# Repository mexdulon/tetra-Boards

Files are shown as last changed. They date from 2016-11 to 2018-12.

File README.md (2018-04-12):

View this project on [CADLAB.io](https://cadlab.io/node/872). 

# tetra-Boards
## mexdulon Modules for Experiments with Digital Electronics

This repository includes material like schematics, layouts, instructions and explanations for mexdulon tetra-Boards. 
The modular system is developed for understanding digital electronics by experimenting. Next to the standard digital components (gates, counter, register, etc.) we created also boards for analog signals and external outputs (motor driver, relay, power FET). All these published boards are licenced as Open Hardware, see below.
If you have any suggestions, modifications or extensions, please feel free to share it with us.

## List with all boards

|Code|Description |
|----|---|
|7SD |7-Segment Display |
|ADA |Adapter 2x5 Port |
|ADC |Analog Digital Converter |
|ADD |Adder 2x4 Bit |
|ALU |Arithmetic Logic Unit |
|AMU |Analog Multiplexer 2x4:1 |
|AND |AND & NAND 4x2:1 |
|ANS |Arduino Nano Shield with Display  |
|ARD |Arduino Shield (Uno, Leonardo) |
|B7D |BCD 7-Segment Decoder |
|BCC |BCD Up/Down Counter |
|BNC |Binary Up/Down Counter 4 Bit |
|BTN |Quad Buttons |
|C12 |Counter 12bit |
|CDL |Counter Divider Logic |
|CLK |Clock Generator |
|CMP |Comparator 2x4 Bit |
|CNT |Dual Counter 4 Bit |
|D12 |Demultiplexer 1:2 |
|D14 |Demultiplexer 1:4 |
|D18 |Demultiplexer 1:8 |
|DAC |Digital Analog Converter (DAC) |
|DEC |Decoder 1:8 |
|DFF |Dual D Flip-flop |
|DIP |DIP Socket |
|DMD |Dot Matrix Display 4x4 |
|DMX |Diode Matrix 4x4 |
|ENC |Encoder 8:3 | 
|FET |Quad Power FET | 
|INV |Dual Inverter (NOT) | 
|IOP |Dual IO Port | 
|JAD |Jumper Adapter | 
|JKF |JK Flip-flop 2x | 
|JMP |Jumper 2x4 |
|JOY |Joystick with Button |
|KEY |Keyboard 4x4 | 
|LAD |Line Adapter | 
|LED |Dual LED Display |
|M81 |Multiplexer 8:1 |
|MTR |Dual Motor Shield |
|MUX |Multiplexer 2:1 |
|MXC |Modulo X Counter (3/6/9/12) | 
|N33 |Tripple NAND 3:1 |
|NOR |OR & NOR 4x2:1 |
|OPA |Operational Amplifier |
|PAN |Dual Port AND 4:1 |
|PIN |Pin Header |
|POR |Dual Port OR 4:1 |
|PRG |Pseudo Random Generator |
|PWM |PWM Generator |
|PXO |Dual Port XOR 4:1 |
|QRS |Quad RS Buttons |
|REG |Register 2x4 |
|RGB |RGB LED & Buzzer |
|RGF |Register File 4x4 |
|RLY |Quad Relay |
|ROM |ROM Diodes 4x4 |
|RSG |RS Generator |
|SAD |Shift Adapter |
|SOC |Quad Socket |
|SRC |SRAM Cell |
|SRG |Shift Register |
|SWG |Square Wave Generator |
|SWI |Quad Switch |
|TMP |Temperature Sensor |
|UNI |Universal Register |
|WNG |White Noise Generator |
|XOR |XOR & XNOR 4x2:1 |

# Copyright and License
Copyright Oliver Krebs 2017.

This documentation describes Open Hardware and is licensed under the CERN OHL v. 1.2. 

You may redistribute and modify this documentation under the terms of the CERN OHL v.1.2. (http://ohwr.org/cernohl). This documentation is distributed WITHOUT ANY EXPRESS OR IMPLIED WARRANTY, INCLUDING OF MERCHANTABILITY, SATISFACTORY QUALITY AND FITNESS FOR A PARTICULAR PURPOSE. Please see the CERN OHL v.1.2 for applicable conditions

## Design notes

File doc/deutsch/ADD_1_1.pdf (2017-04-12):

# Adder v1.1

mexdulon

12. April 2017

1

mexdulon | 1 ADDER

## 1 Adder

### 1.1 Allgemein

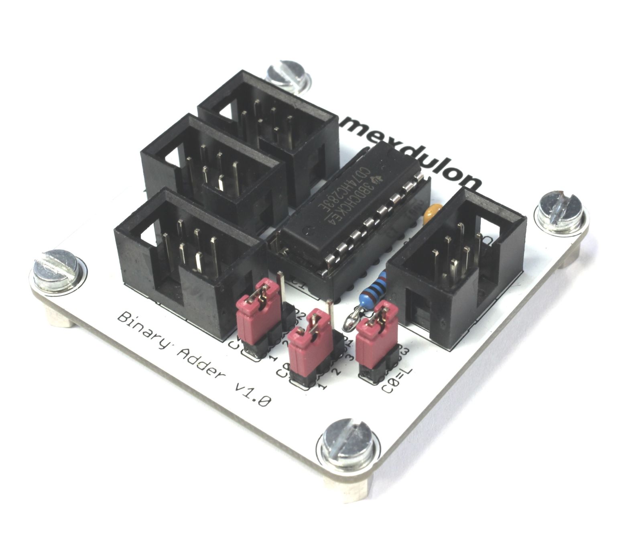
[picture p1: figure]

Wie der Name schon vermuten lässt, kann der Adder Zahlen addieren. Ein einzelnes Adder-Boardkann die zwei Zahlen derEingängeInAundInBaddieren undgibt dasErgebnis auf dem Ausgang Out aus.

### 1.2 Funktion

Die beiden 4-Bit Zahlen A und B sowie das Bit C0werden binär addiert. Für die gewöhnliche 4-Bit Addition wird C0 auf Low gesetzt. Die Summe liegt am Ausgang Out an, das Overflow Bit C4 kann auf dem Port Carry ausgegeben werden. Dieses zeigt mit einem High an, dass das Ergebnis größer ist, als am Ausgang dargestellt werden kann (also größer als 15). Über die Verknüpfung von C0 und C4 können außerdemmehrere Addierer zusammengeschaltet werden, um größere Zahlen als 4-Bit zu addieren. Dafür muss der Addierer für das niedrigwertigere Nibble das C4 dort ausgeben, wo der nächsthöhere Addierer das C0 erwartet. Ein möglicher Aufbau für einen 12-Bit Addierer wäre z. B. wie folgt:

Adder | C0 | C4 | Daten
1 | L | 1 | Bit 0..3
2 | 1 | 2 | Bit 4..7
3 | 2 | - | Bit 8..11

Hier wird dann allerdings noch einAdapter benötigt, um die Carry-Signale zu verteilen. Für einen 8-Bit Addierer können die beiden Carry Ports der beiden Adder direkt verbunden werden.
Der Adder kann übrigens auch zum Subtrahieren eingesetzt werden, also A minus B rechnen. Dafür muss der Eingang B invertiert werden und C0 auf High gesetzt werden. Das Invertieren kann man mit einem XOR Gatter auch schaltbar machen. Wenn man dann das Schaltsignalmit Carry verbindet,kannmanwahlweiseaddierenoder subtrahieren. Beachte allerdings, dass das Ergebnis der Subtraktion negativ sein kann und dann die Zuordnung Bitmuster-Wert anders ist (1111 ist dann nicht 15 sondern -1)!

2

mexdulon | 1 ADDER

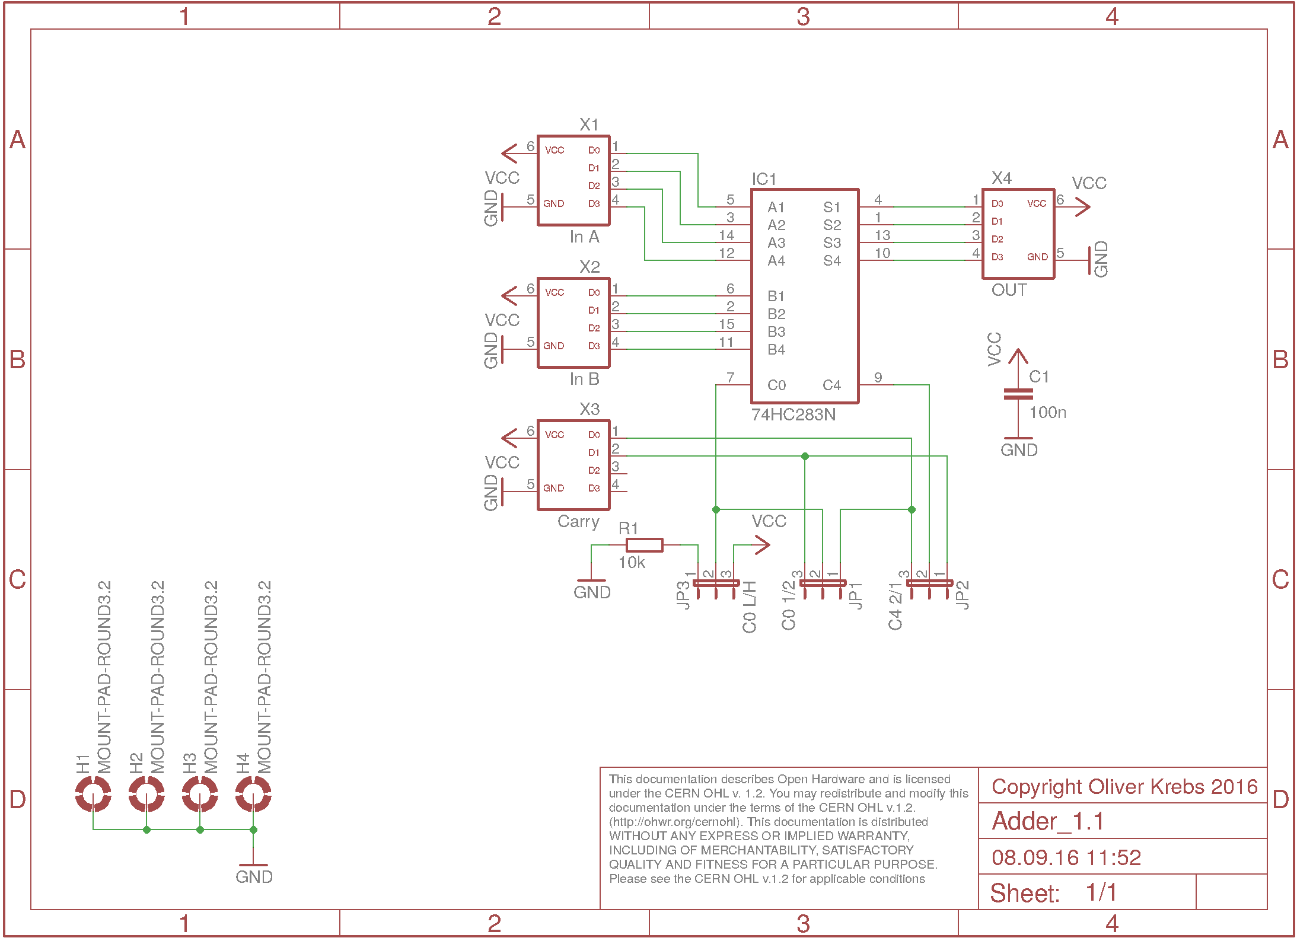
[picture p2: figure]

### 1.3 Aufbau

Kürzel | Wert | Bezeichnung
C1 | 100n | Kondensator
IC1 | 74HC283N | IC (Addierer)
JP1 | C0 1/2 | Stiftleiste 1x3
JP2 | C4 2/1 | Stiftleiste 1x3
JP3 | C0 L/H | Stiftleiste 1x3
R1 | 10k | Widerstand
X1 | In A | Wannenstecker
X2 | In B | Wannenstecker
X3 | Carry | Wannenstecker
X4 | OUT | Wannenstecker

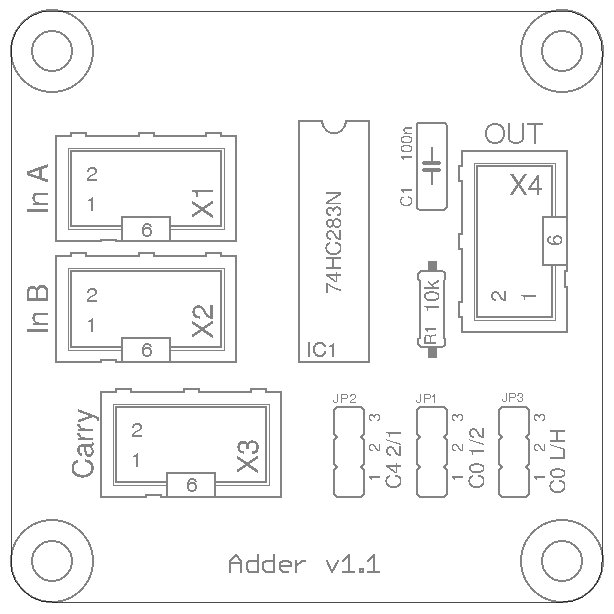
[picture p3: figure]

### 1.4 Test

Um das Board zu testen, sollten verschiedene Eingangswerte gesetzt werden und die Ausgabe mit einem LED Display überprüft werden. Die beiden Eingänge In A und In B werden mit einem Jumper-Board verbunden. Der Port Carry bleibt unbelegt, mit dem Jumper JP3 wird C0 auf L(Low) gesetzt(JP3 1-2). Nun sollten sich in Abhängigkeit der amJumper-Board gesetzten Werte entsprechend die Ausgabe ändern:

3

mexdulon | 1 ADDER
In A | In B | Out
0000 | 0000 | 0000
0000 | 0001 | 0001
0010 | 0001 | 0011
0010 | 1011 | 1101
(a) Binäre Werte
In A | In B | Out
0 | 0 | 0
0 | 1 | 1
2 | 1 | 3
2 | 11 | 13
(b) Dezimale Werte

Tabelle 1: Werte für Test

4

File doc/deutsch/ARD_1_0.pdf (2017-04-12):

# Arduino Shield v1.0

mexdulon

12. April 2017

1

mexdulon | 1 ARDUINO SHIELD

## 1 Arduino Shield

### 1.1 Allgemein

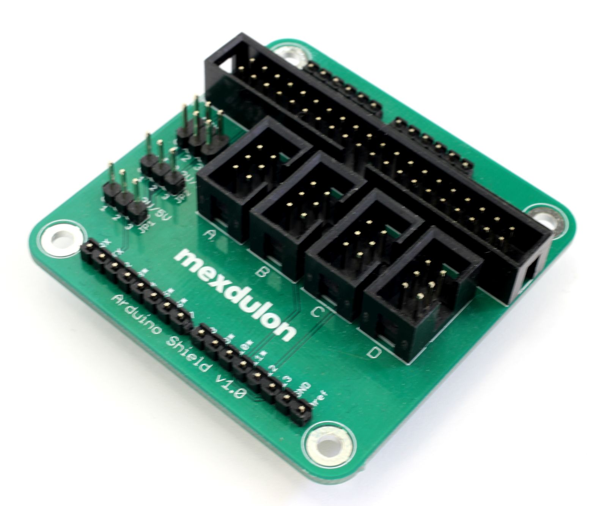
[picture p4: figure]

Das Arduino Shield ist ein Modul für die Kombination von mexdulon tetra-Boards mit einem Arduino oder einem Raspberry Pi. Es kann auf einen Arduino Uno, Leonardo oder kompatible Boards aufgesteckt bzw. mit einem Raspberry Pi verbunden werden. Bis zu vier Ports können dann als variable Eingänge oder Ausgänge programmiert werden.

### 1.2 Funktion

### 1.2.1 Arduino Shield

Das Board wird auf den gewünschten Arduino aufgesteckt und dient dann als Schnittstelle zuweiteren tetra-Boards.Die einzelnen PortsA bisDkönnen variabelals(digitale)Eingänge oder Ausgänge genutzt werden. Port A kann auch für analoge Eingangswerte und Port D für die Ausgabe von PWM genutzt werden. Zum einfachen Einstieg steht eine Library sowie einige Beispiele für die Arduino Programmierung bereit. Wird der Arduino mit Spannung versorgt, kann er für die Versorgung der tetra-Boards mitgenutzt werden. Dafür steht die Stiftleiste JP1 zur Verfügung, die dann mit einem Jumper auf A 5V (JP1 2-3) gesetzt wird. Achtung: Die meisten Arduino arbeiten mit 5 V, die Spannung 3.3 V sollte nur in Ausnahmefällen gewählt werden.Wenn das Arduino-Board allerdings mit 3.3 V arbeitet, kann der Arduino bei 5 V Schaden nehmen! Insbesondere dürfen niemals verschiedene Spannungen gleichzeitig verwendet werden. So ist z. B. Spannung über USB vom Jumper-Board (5 V) und im gleichen Schaltkreis Versorgung über den Arduino mit 3.3 V verboten. Verwende immer nur eine Spannungsquelle(USB-Netzteil oder Powerbank).

### 1.2.2 Raspberry Pi Shield

Das Shield ist so ausgelegt, dass es auch mit einem Raspberry Pi verbunden werden kann. Dafür muss der optionale 40-polige Wannenstecker bestückt werden und ein Flachbandkabel zum Verbinden genutzt werden. Da der Raspberry Pi jedoch mit 3.3 V arbeitet, ist es wichtig keine zusätzliche 5 V Quelle einzusetzen! Anstelle dessen sollte ein Jumper auf

2

mexdulon | 1 ARDUINO SHIELD

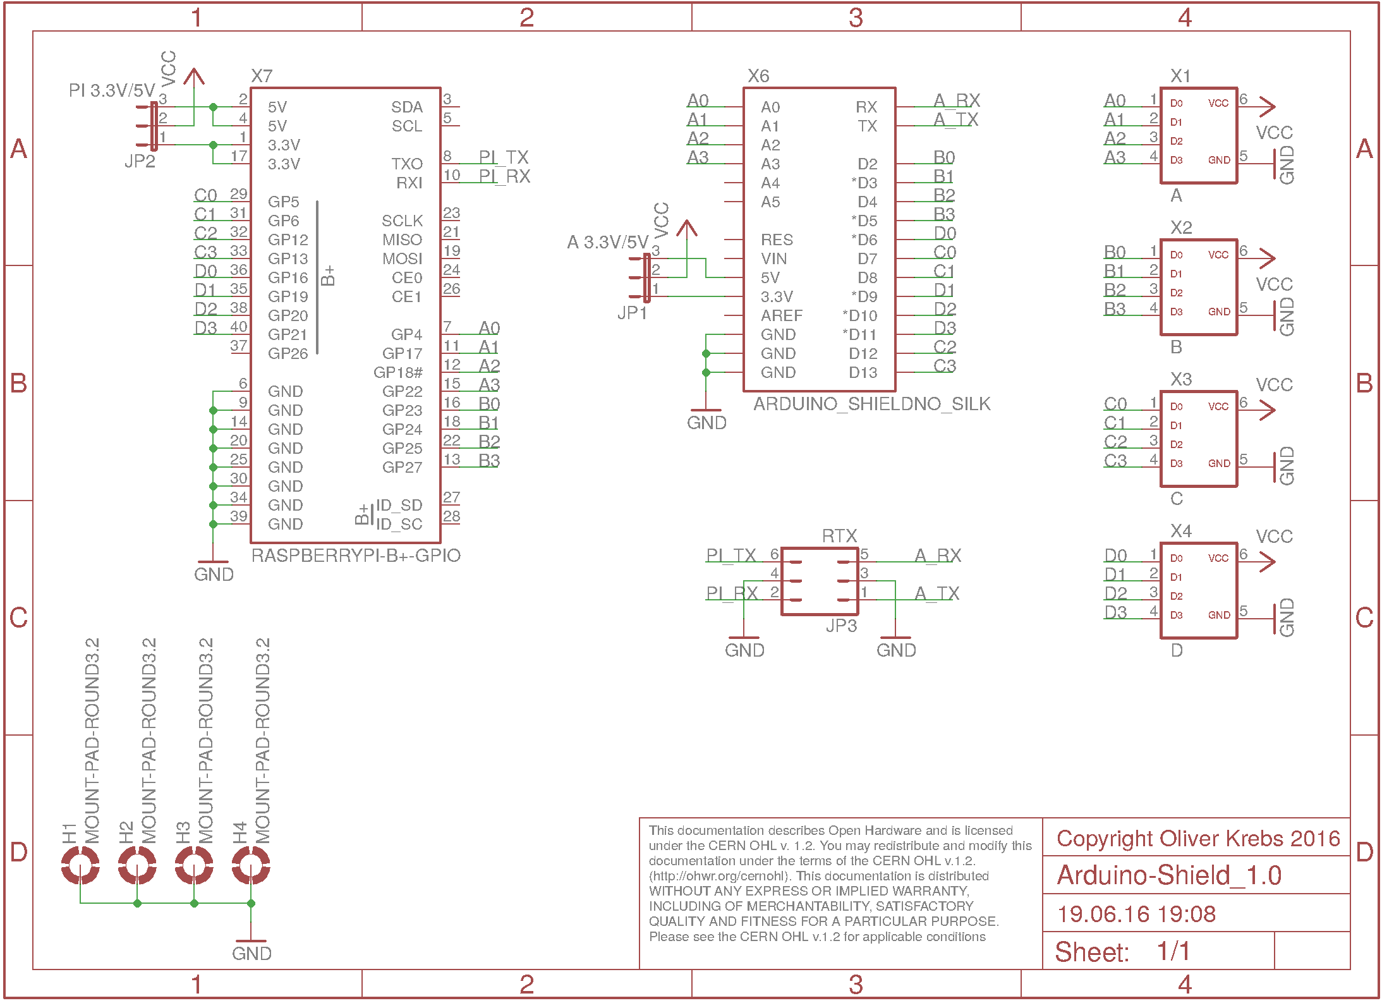
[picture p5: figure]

PI 3.3V (JP2 1-2) gesetzt werden. Da die Spannung dann geringer ist, werden LED und Displays übrigens schwächerleuchten!Wirempfehlen dieNutzung der BoardsmiteinemRaspberry Pi nur erfahrenen Anwendern.

### 1.3 Aufbau

3

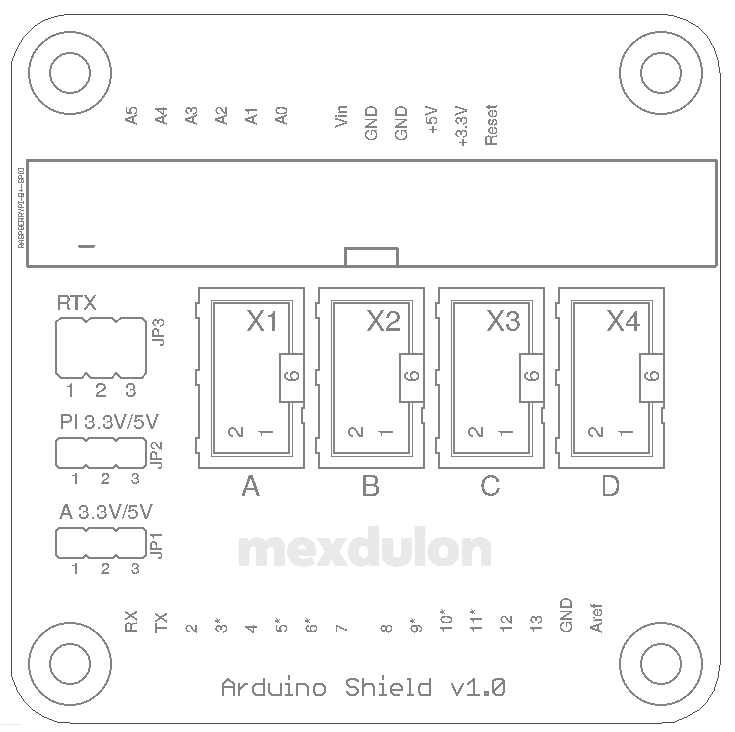
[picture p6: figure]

mexdulon | 1 ARDUINO SHIELD
Kürzel | Wert | Bezeichnung
JP1 | A 3.3V/5V | Stiftleiste 1x3
JP2 | PI 3.3V/5V | Stiftleiste 1x3
JP3 | RTX | Stiftleiste 2x3
X1 | A | Wannenstecker
X2 | B | Wannenstecker
X3 | C | Wannenstecker
X4 | D | Wannenstecker
X6 | ARDUINO_SHIELD | Stiftleisten (Arduino)
X7 | RASPBERRYPI-B+-GPIO | Wannenstecker¹

Beginne beim Aufbau mit den Stiftleisten JP1, JP2 und JP3. Danach folgen dieWannenstecker für die Ports A bis D. Optional kann ein langer Wannenstecker (40-polig, nicht im Bausatz enthalten) für den Raspberry Pi eingelötet werden. Zum Schluss folgen die 6- und 8-poligen Stiftleisten für die Verbindung zum Arduino. Diese werden von unten eingesetzt und von oben gelötet, damit das Shield auf den Arduino aufgesteckt werden kann.

### 1.4 Test

Um dasArduinoShieldzu testen,wirdeinArduinoUnooder Leonardo undein BoardRGB& Buzzer benötigt. Das Shield wird auf den Arduino aufgesteckt und Port Amit dem Eingang RGB verbunden. Die Library mexdulon von GitHub muss heruntergeladen und in der Arduino IDE installiertwerden.Dann kann das Beispiel ExampleRGB kopiert, kompiliert und auf den Arduino übertragen werden. Nun sollten abwechelnd im Sekundentakt die Farbe der RGB-LED durchwechseln. Wer auch die anderen Ports testen möchte, kann den Port für RGB ändern:
#include <Mexdulon.h>

MexRGB mexRGB(MEX_PORT_B );

4

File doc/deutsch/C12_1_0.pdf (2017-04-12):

# Counter 12 Bit v1.0

# mexdulon

12. April 2017

1

mexdulon | 1 COUNTER 12-BIT

## 1 Counter 12-Bit

### 1.1 Allgemein

Counter 12-Bit ist ein Board für das binäre Hochzählen von 0 bis 4095 (12 Bit). Der Zähler kann jederzeit über ein Signal zurückgesetzt werden.

### 1.2 Funktion

Über den EingangCtrlwird dasTaktsignal zumHochzählen eingegeben.Optional kann hier auf Pin 3 das Rücksetz-Signal mitgegeben werden. Dafür muss der Jumper Clr C2 (JP1 1-2) gesetzt werden. Steht der Jumper auf Clr L (2-3), ist Rücksetzen deaktiviert. Die Ausgänge Out A, Out B und Out C enthalten den aktuellen Zählerstand. Dabei sind A die Bits 0 bis 3, B sind 4 bis 7 und C die Bits 8 bis 11. Die genaue Zuordnung steht in Tabelle 1:
Bit Wert | Pin
0 | 1 | A1
1 | 2 | A2
2 | 4 | A3
3 | 8 | A4
4 | 16 | B1
5 | 32 | B2
6 | 64 | B3
7 | 128 | B4
8 | 256 | C1
9 | 512 | C2
10 1024 | C3
11 2048 | C4

Tabelle 1: Zuordnung Pins

Bitmuster | Dezimalwert
0000 0000 0000 | 0
0000 0000 0001 | 1
0000 0000 0010 | 2
0000 0000 0011 | 3
0000 0000 0100 | 4
1111 1111 1110 | 4094
1111 1111 1111 | 4095
0000 0000 0000 | 0
0000 0000 0001 | 1
0000 0000 0010 | 2

Tabelle 2: Zählweise

Der Zählererhöht denWertmitjeder positivenTaktflanke(Wechsel von Low nachHigh) an Ctrl-1. Ist das Rücksetzsignal Clr High, wird der Zähler auf 0 zurückgesetzt. Andernfalls wird bis 4095(alle 12 BitsHigh) hochgezählt und danachwieder bei 0 begonnen. Die binäre Zählweise ist in Tabelle 2 abgebildet.

2

mexdulon | 1 COUNTER 12-BIT

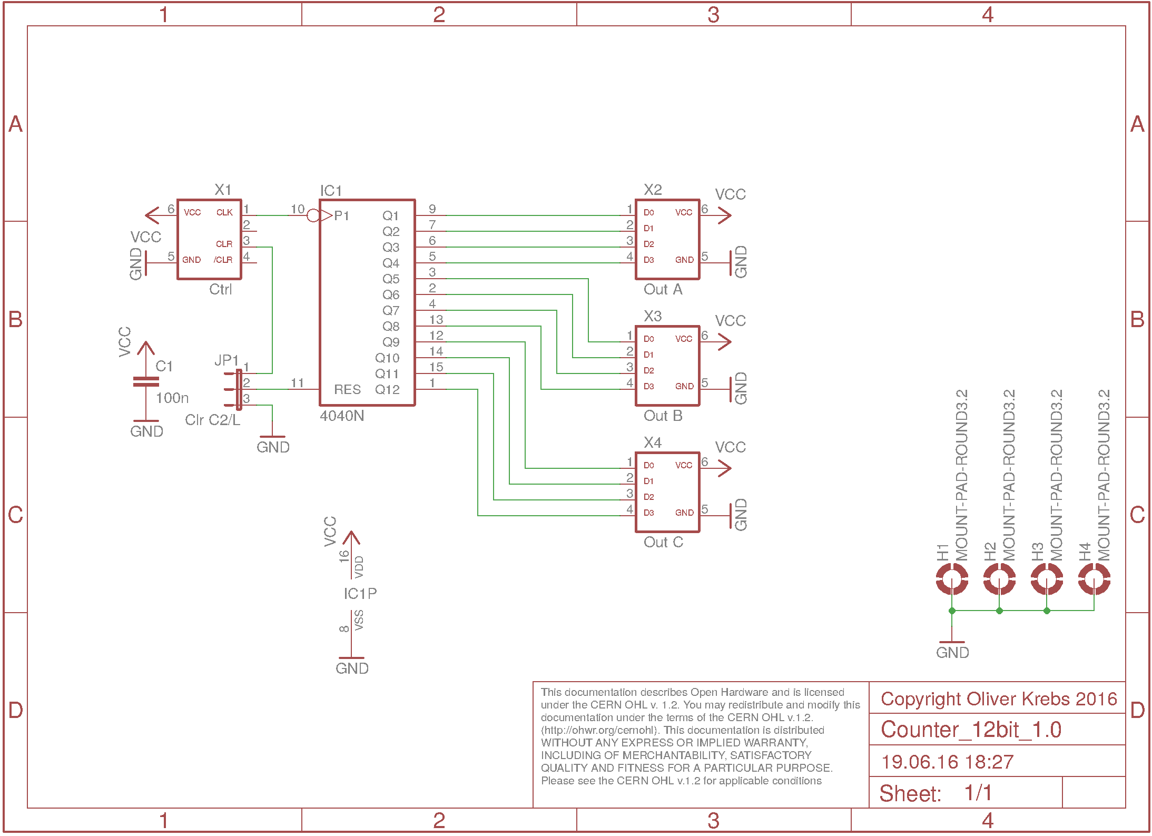
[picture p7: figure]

### 1.3 Aufbau

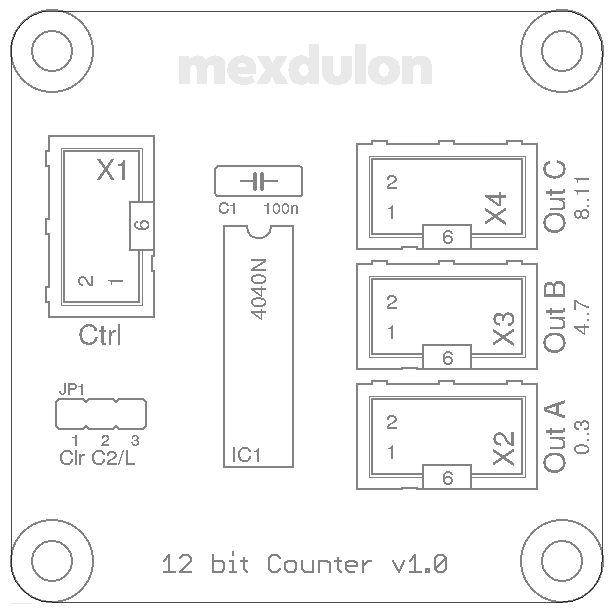
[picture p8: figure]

Kürzel | Wert | Bezeichnung
C1 | 100n | Kondensator
IC1 | 4040N | IC (Counter)
JP1 | Clr C2/L | Stiftleiste 1x3
X1 | Ctrl | Wannenstecker
X2 | Out A | Wannenstecker
X3 | Out B | Wannenstecker
X4 | Out C | Wannenstecker

3

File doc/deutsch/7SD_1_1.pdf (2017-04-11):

# 7-Segment Display v1.1

mexdulon

8. April 2017

1

mexdulon | 1 7-SEGMENT DISPLAY

## 1 7-Segment Display

### 1.1 Allgemein

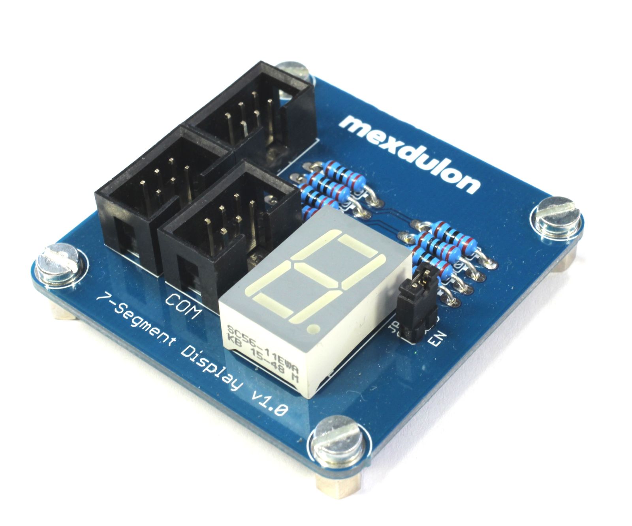
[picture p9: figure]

Das 7-Segment Display (abgekürzt auch 7SD) ist dazu gedacht die Ziffern 0-9 und optional einen Punkt (’.’) darzustellen. Solche Anzeigen kennt der eine oder andere vielleicht aus digitalen-Armbanduhren (hier als LCD Variante) oder der Uhr auf dem Nachttisch. Es sind übrigens auch zusätzliche Zeichen wie z. B. einige Buchstaben darstellbar.
In B Pin | In A Pin | Segment
| 1 | a
| 2 | b
| 3 | c
| 4 | d
1 | | e
2 | | f
3 | | g
4 | | DP (Punkt)

### 1.2 Funktion

Die Anzeige besteht im Grunde genommen aus 8 einzelnen LED. Jede einzelne dieser LED muss zur gewünschten Darstellung geschaltet werden. Dies benötigt zwei eingehende Datenworte,je eins aufInAundIn B.Mit nur einem gesteckten Kabel kann es zumerkwürdigen Ausgaben kommen.Sollte es trotz beidergesteckten Kabel zu komischenDarstellungenauf der Anzeige kommen, könnte ein Vertauschen der Kabel die Ursache sein. Wenn auch ein Umstecken nichts verbessert und immer noch komische Dinge erscheinen, könnte ein falsches Board unmittelbar vor den Eingängen des Anzeige-Boards dafür verantwortlich sein. Nur wenn die Ansteuerung ordentlich ist, kommen auch lesbare Zeichen heraus. Für die meisten Zwecke wird eine Umwandlung von binären Dezimalzahlen (BCD) auf 7-Segment gewünscht sein, dies erledigt der BCD 7SD Decoder.

2

mexdulon | 1 7-SEGMENT DISPLAY

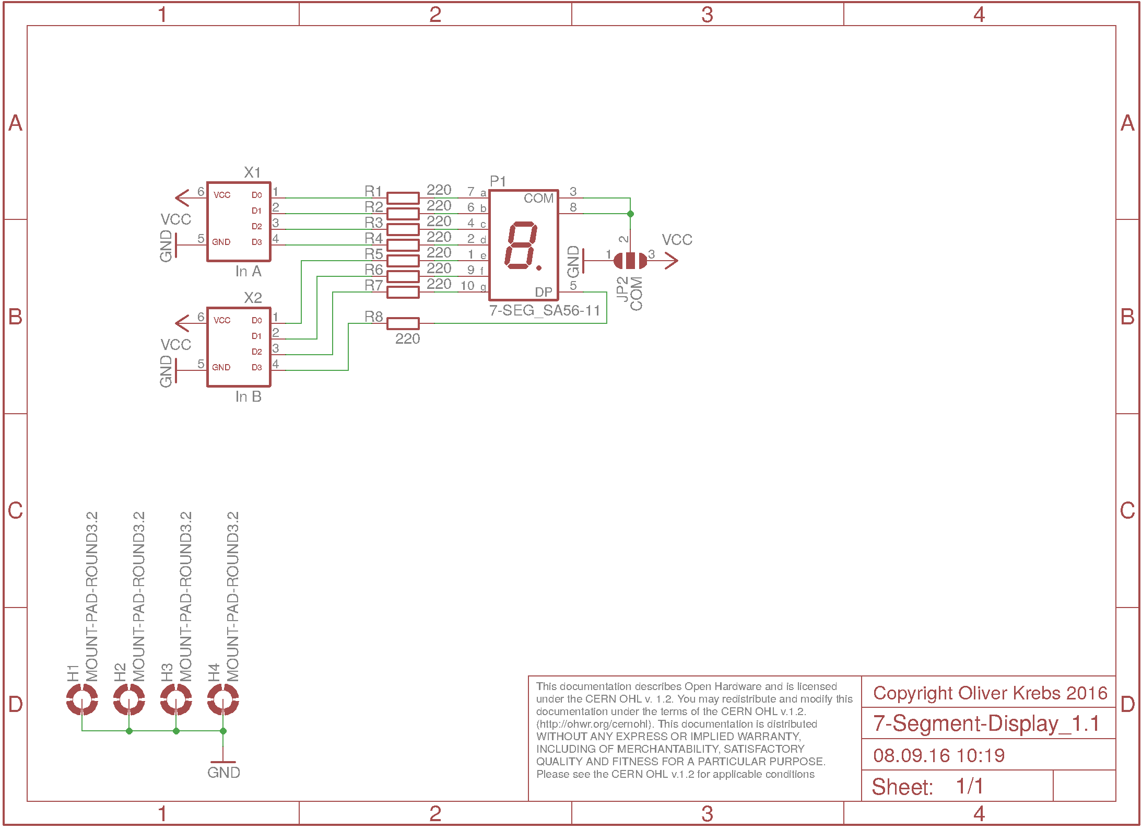
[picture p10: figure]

### 1.3 Aufbau

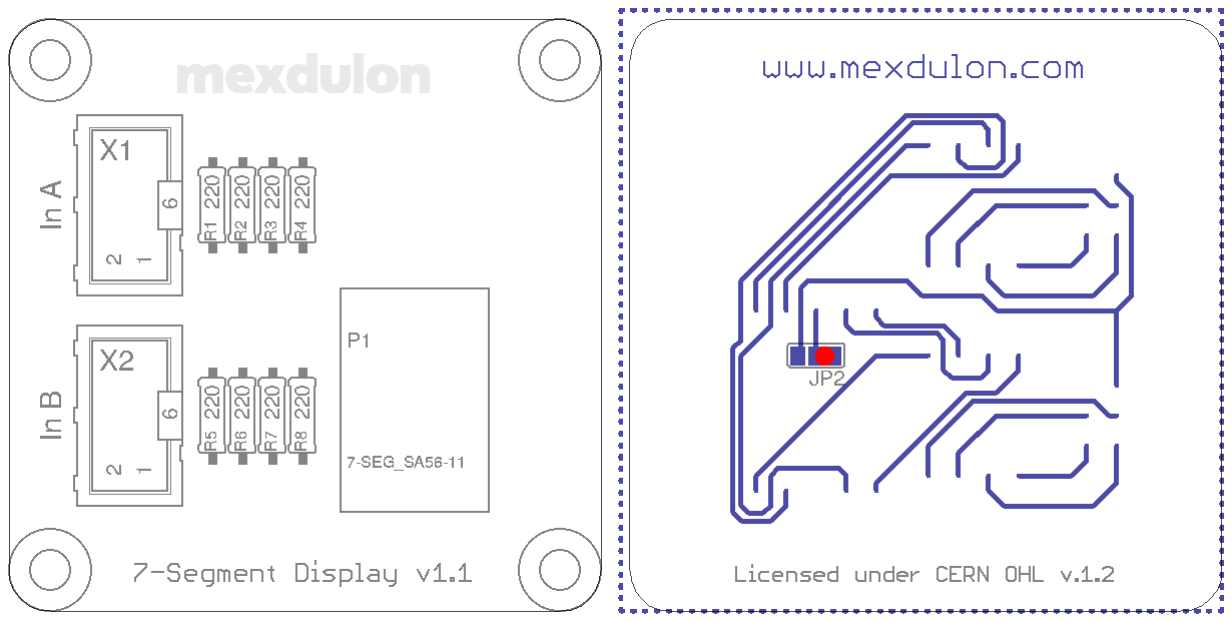
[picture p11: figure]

3

mexdulon | 1 7-SEGMENT DISPLAY
Kürzel | Wert | Bezeichnung
P1 | 7-SEG_SC56-11 | 7-Segment Display
R1 | 220R | Widerstand
R2 | 220R | Widerstand
R3 | 220R | Widerstand
R4 | 220R | Widerstand
R5 | 220R | Widerstand
R6 | 220R | Widerstand
R7 | 220R | Widerstand
R8 | 220R | Widerstand
X1 | In A | Wannenstecker
X2 | In B | Wannenstecker
Der Aufbau beginnt mit den 8 Widerständen R1 bis R8. Dann gibt es auf der Rückseite der Platine einen sogenannten Solder-Jumper ('Lötjumper’) JP2. Hier muss der Anschluss des Displays 'COM’mit der Masse verbundenwerden, da es sich um ein Displaymit gemeinsamer Kathode handelt. Dafür muss JP2 von 1 zu 2 (Mitte nach innen, also dort wo JP2 aufgedruckt ist)mit etwas Lötzinn überbrücktwerden(siehe Abbildung).Danachwird dasDisplay eingesetzt und festgelötet. Achte dabei auf die richtige Ausrichtung(Punkt nach unten rechts). Zum Schluss werden noch die beidenWannenstecker ergänzt und das Board ist fertig.

### 1.4 Test

Zum Testen kann man die beiden Eingänge In A und In B des Displays an ein Jumper Board anschließen.Werden alle Steckbrücken gesetzt, sollten alle Segmente leuchten, also eine 8 und der Punkt sichtbar sein.

4

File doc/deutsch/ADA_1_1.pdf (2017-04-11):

# Adapter v1.1

mexdulon

8. April 2017

1

mexdulon | 1 ADAPTER

## 1 Adapter

### 1.1 Allgemein

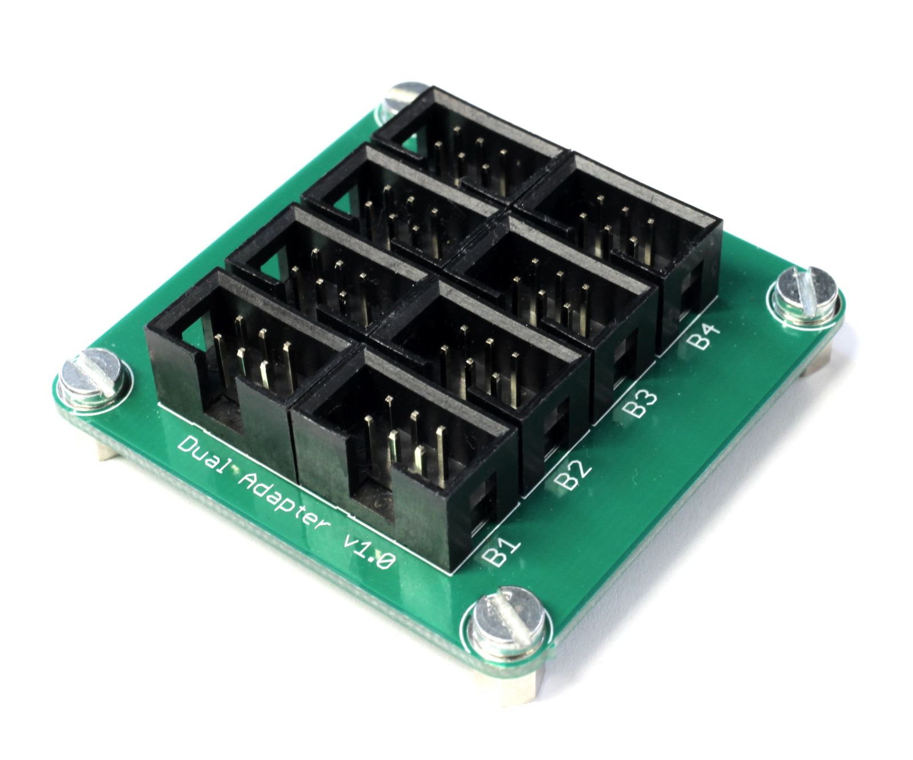
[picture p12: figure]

Das Board Adapter kanngenutztwerden, umSignale bzw.Datenworte aufmehrereEingänge zu verteilen. Dafür stehen zwei Kanäle A und B mit jeweils 5 Ports zur Verfügung.

### 1.2 Funktion

Der Adapter ist ein Baustein für variable Verbindungen, er enthält keine aktiven Komponenten. Jeweils 5 Ports stehen für die Kanäle A und B bereit, die alle 1:1 verbunden sind. Die Signale sind zwischen A und B getrennt, jedoch nicht die Versorgung. Verbinde den Ausgang eines Boards mit dem Adapter und die weiteren Ports mit bis zu 4 Eingängen. So kannst du bspw. ein Taktsignal von SquareWave für den Takteingang mehrerer Boards nutzen.
Achtung:VerbindeniemalsmehrereAusgängemiteinanderüberdenAdapter.Möchtestdumehrere Ausgänge verknüpfen, benötigst du ein anderes Board (z.B. OR oder AND).

### 1.3 Aufbau

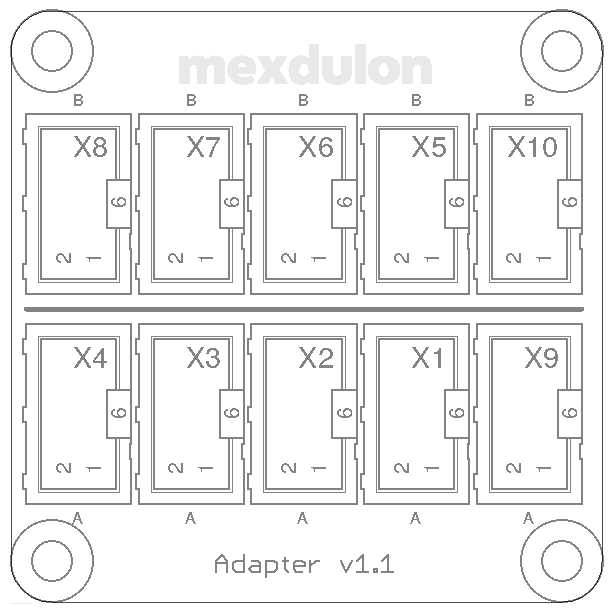
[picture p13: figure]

Kürzel | Wert | Bezeichnung
X1 | A | Wannenstecker
X2 | A | Wannenstecker
X3 | A | Wannenstecker
X4 | A | Wannenstecker
X5 | B | Wannenstecker
X6 | B | Wannenstecker
X7 | B | Wannenstecker
X8 | B | Wannenstecker
X9 | A | Wannenstecker
X10 | B | Wannenstecker

2

mexdulon | 1 ADAPTER

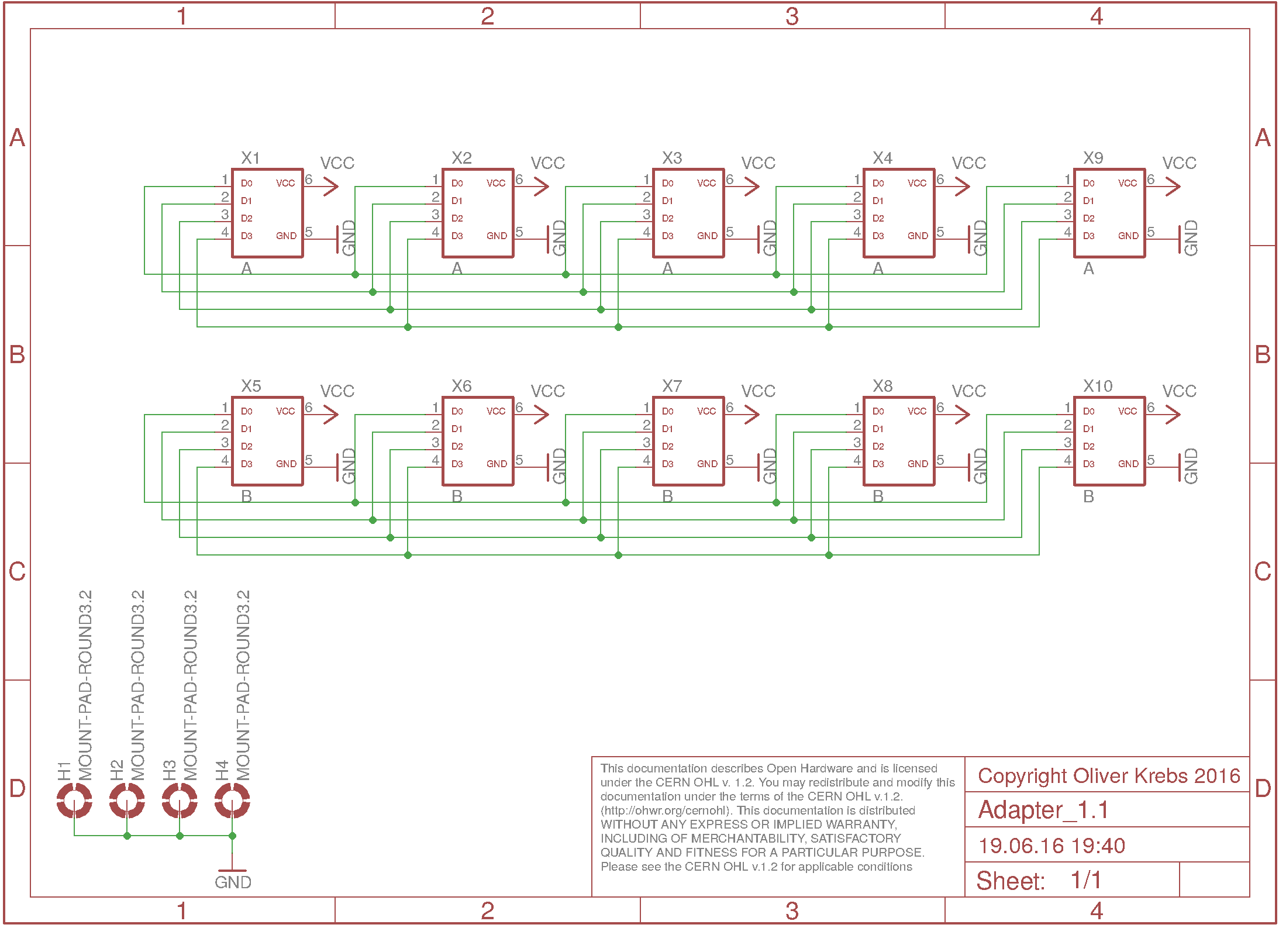
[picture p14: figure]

3

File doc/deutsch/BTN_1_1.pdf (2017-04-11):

# Button v1.1

mexdulon

8. April 2017

1

mexdulon | 1 BUTTON

## 1 Button

### 1.1 Allgemein

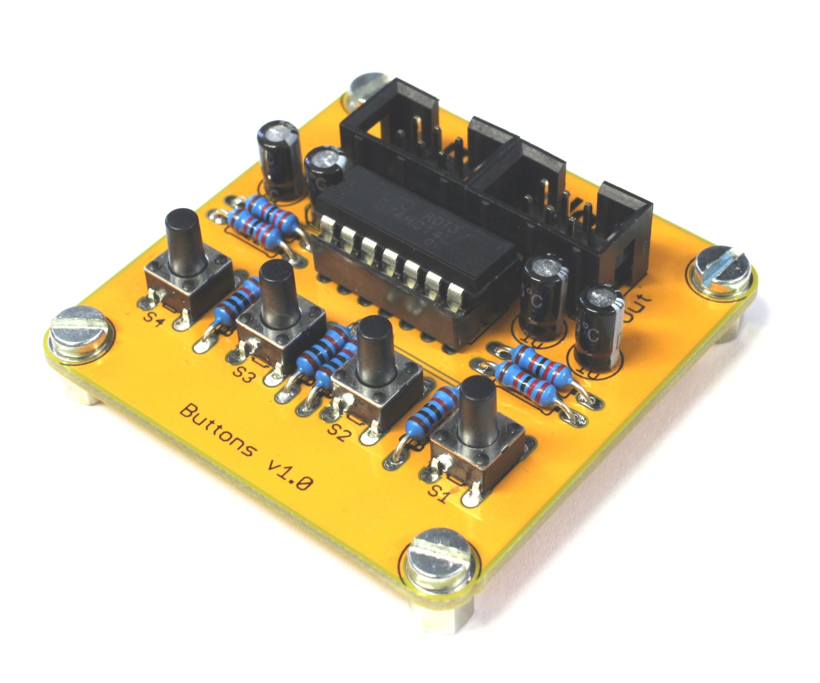
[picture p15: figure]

Das BoardButtonsenthält vierTaster, die für Benutzereingaben verwendetwerdenkönnen. So sind temporäre Datenworte oder Schalt- bzw. Taktsignale damit realisierbar.

### 1.2 Funktion

Solange ein Taster gedrückt ist, ist das entsprechende Signal High (1), sonst ist es Low (0). Die Taster sind entprellt, sodass sie auch für flankengesteuerte Signale verwendet werden können(z. B. Takt).Die beiden PortsOutsind Ausgänge, die 1:1 verbunden sind und entsprechend parallel genutzt werden können.

Taster | Signal | Spannung | Logik
Nicht gedrückt | Low | GND (0 V) | 0 (falsch)
Gedrückt | High | VCC (5 V) | 1 (wahr)

2

mexdulon | 1 BUTTON

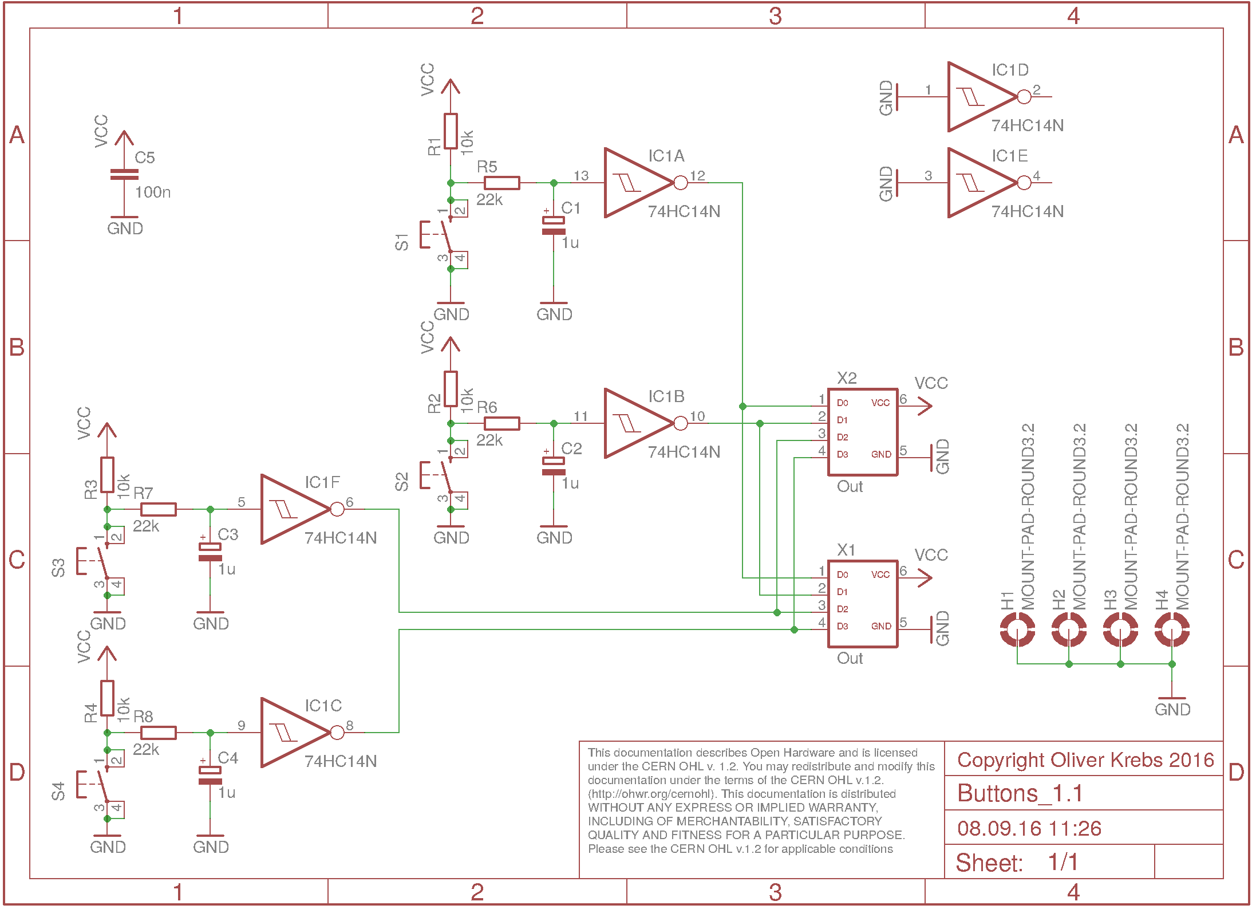
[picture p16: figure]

### 1.3 Aufbau

Kürzel | Wert | Bezeichnung
C1 | 1u | Elko
C2 | 1u | Elko
C3 | 1u | Elko
C4 | 1u | Elko
C5 | 100n | Kondensator
IC1 | 74HC14N | IC (Schmitt Inverter)
R1 | 10k | Widerstand
R2 | 10k | Widerstand
R3 | 10k | Widerstand
R4 | 10k | Widerstand
R5 | 22k | Widerstand
R6 | 22k | Widerstand
R7 | 22k | Widerstand
R8 | 22k | Widerstand
S1 | | Taster
S2 | | Taster
S3 | | Taster
S4 | | Taster
X1 | Out | Wannenstecker
X2 | Out | Wannenstecker

3

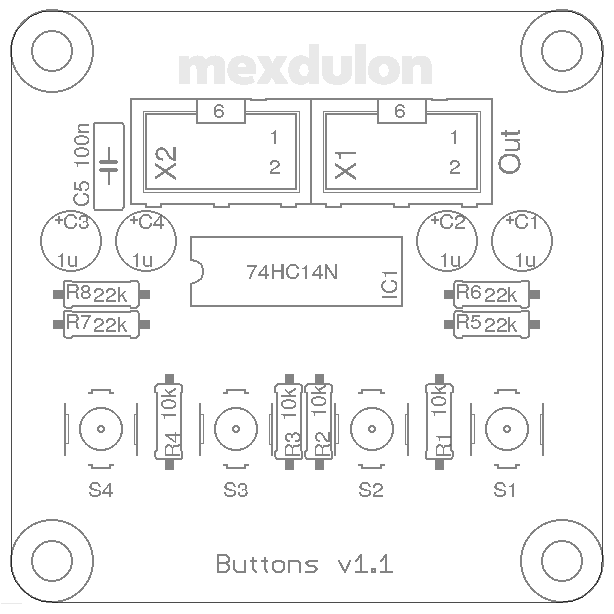
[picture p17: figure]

mexdulon | 1 BUTTON

### 1.4 Test

Verbinde einen Ausgang des Boards mit In A eines LED Displays. Verbinde an den zweiten EingangInBdes LEDDisplayseinJumperBoard.Schalte dieSpannungsquelleein und prüfe, ob die LED bei Tastendruck leuchten. Taster S1 sollte mit LED P1 verknüpft sein, S2 mit P2, S3 mit P3 und S4 mit P4.

4

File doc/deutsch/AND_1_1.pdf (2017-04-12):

# AND & NAND v1.1

mexdulon

12. April 2017

1

mexdulon | 1 AND & NAND

## 1 AND & NAND

### 1.1 Allgemein

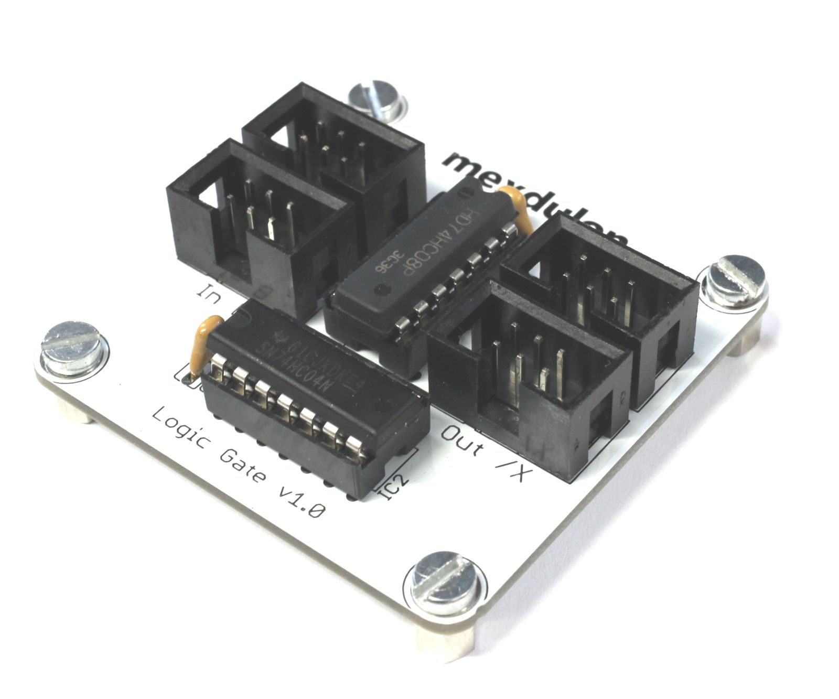
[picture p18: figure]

Das Board AND & NAND enthält Gatter für die logische Verknüpfung von zwei Datenworten. Die kombinierten Ausgänge sind AND und NAND.

### 1.2 Funktion

Der Baustein enthält 4 UND-Gatter mit jeweils 2 Eingängen und einen 4-fachen Inverter. Die Signale der beiden Eingänge In A und In Bwerden wie folgt verknüpft: A1 mit B1, A2 mit B2, A3 mit B3 und A4 mit B4. Das mit der UND-Funktion kombinierte Datenwort liegt an AND an. Am zweiten Ausgang NAND liegt das dazu invertierte Datenwort an. Die beiden Funktionen sind in folgender Wahrheitstabelle zusammengefasst:

A | B | AND | NAND
L | L | L | H
L | H | L | H
H | L | L | H
H | H | H | L

2

mexdulon | 1 AND & NAND

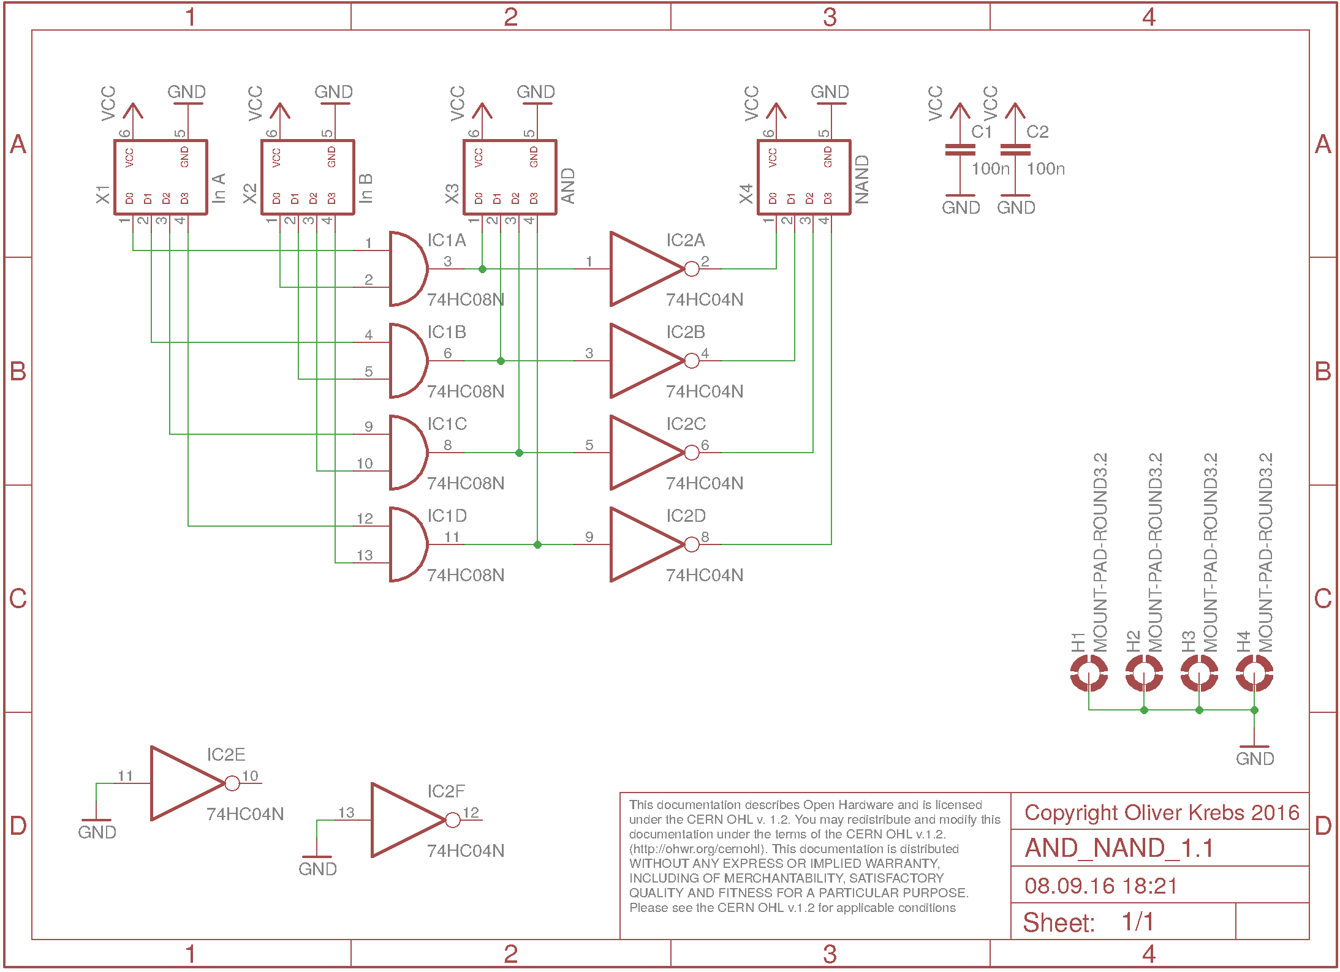
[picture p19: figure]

### 1.3 Aufbau

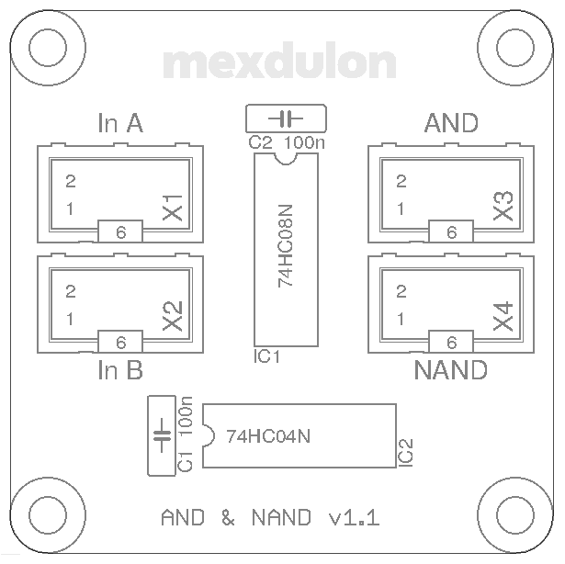
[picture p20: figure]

Kürzel | Wert | Bezeichnung
C1 | 100n | Kondensator
C2 | 100n | Kondensator
IC1 | 74HC08N | IC (AND)
IC2 | 74HC04N | IC (Inverter)
X1 | In A | Wannenstecker
X2 | In B | Wannenstecker
X3 | AND | Wannenstecker
X4 | NAND | Wannenstecker

3

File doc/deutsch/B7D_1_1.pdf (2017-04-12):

# BCD 7SD Decoder v1.1

mexdulon

12. April 2017

1

mexdulon | 1 BCD 7SD DECODER

## 1 BCD 7SD Decoder

### 1.1 Allgemein

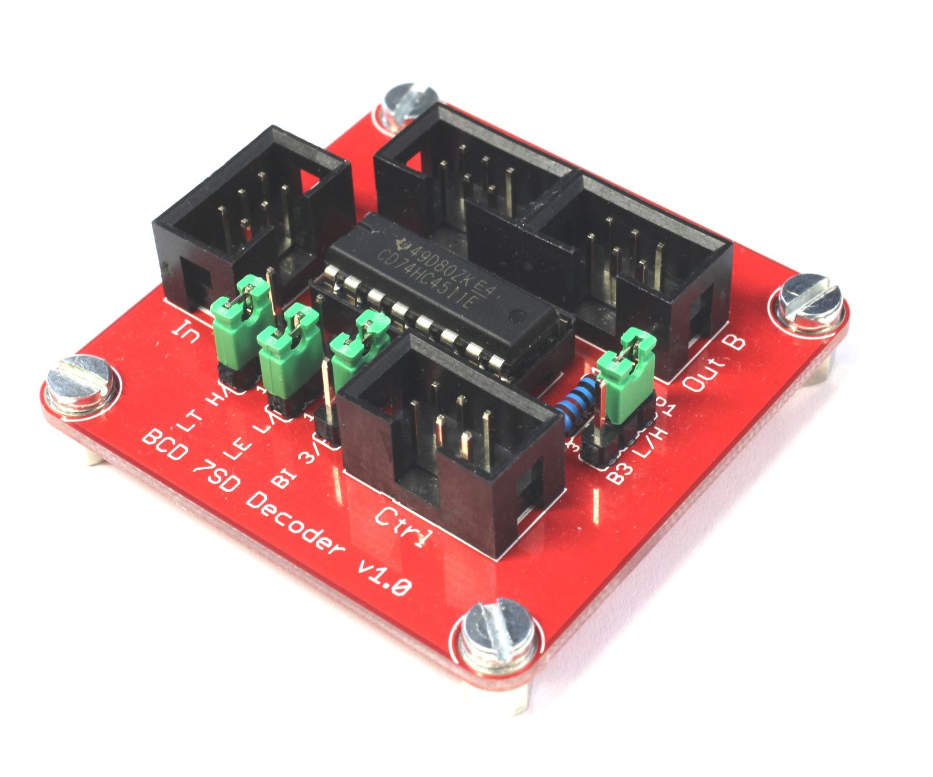
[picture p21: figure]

Der BCD 7SD Decoder (BCD 7-Segment-Display Decoder) wandelt ein binäres Datenwort für die dezimale Anzeige auf einem 7-Segment Display um.

### 1.2 Funktion

Über den Eingang In können binäre Werte von 0 bis 9 (BCD) eingegeben werden. Der entsprechende Wert wird für die Darstellung auf einem7-Segment Display umgewandelt und dazuaufOutAundOutBausgegeben.An dieseAusgängekönnen dieEingänge des 7-Segment Displays angeschlossen werden, um dieWerte dort dezimal auszugeben. Über die Stiftleiste JP1 kann Pin 4 von Out B (am Display der Dezimalpunkt) auf Low oder High gesetzt werden.

### 1.3 Aufbau

Kürzel | Wert | Bezeichnung
C1 | 100n | Kondensator
IC1 | 4511N | IC (Decoder)
JP1 | B4 L/H | Stiftleiste 1x3
R1 | 10k | Widerstand
X1 | In | Wannenstecker
X3 | Out A | Wannenstecker
X4 | Out B | Wannenstecker

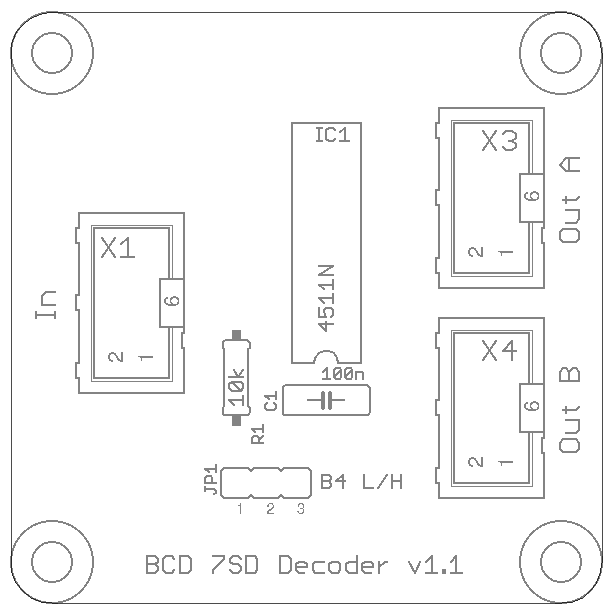
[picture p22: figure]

### 1.4 Test

Um das Board zu testen, kann die Ausgabe auf einem7-Segment Display bei verschiedenen Eingabewerten überprüftwerden. Verbinde dazu einJumperBoardmit demEingangInund

2

mexdulon | 1 BCD 7SD DECODER

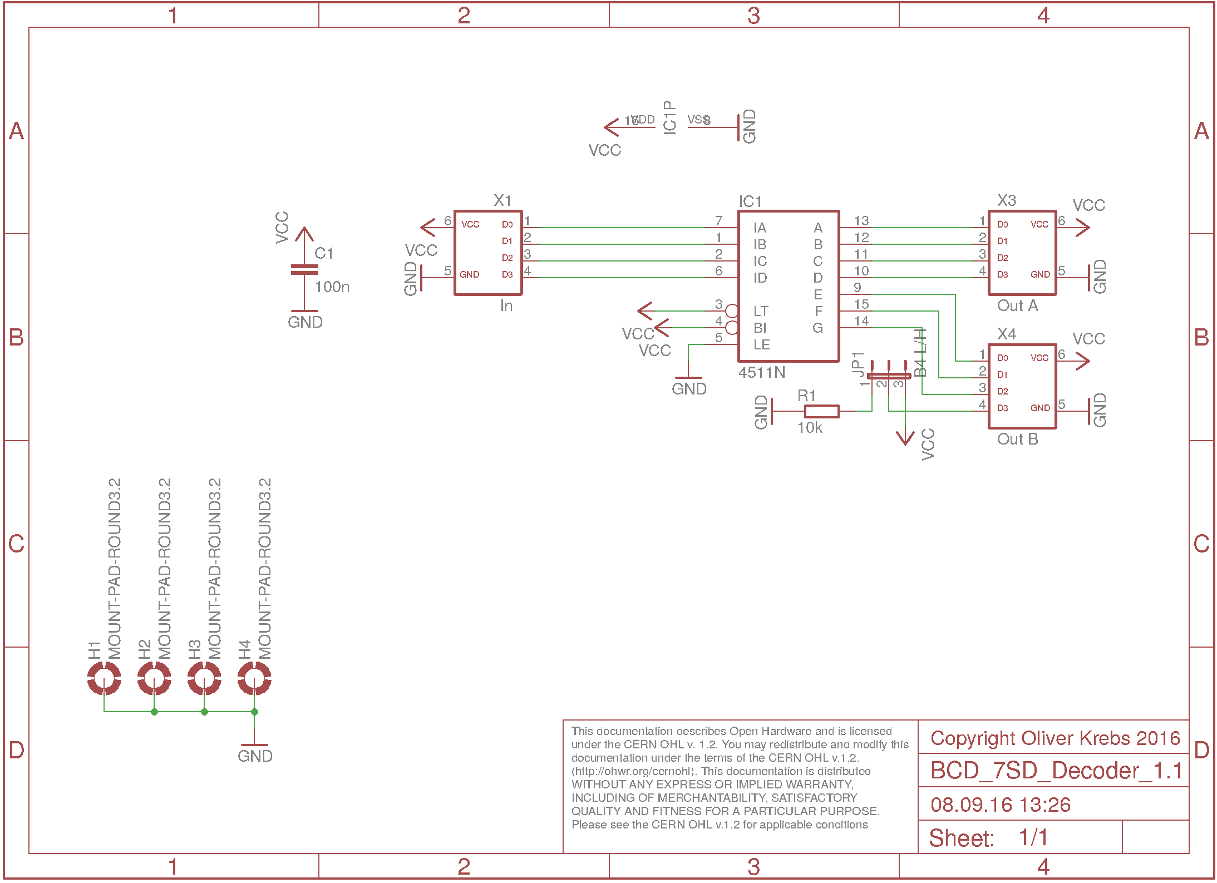
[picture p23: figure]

die Ausgänge mit den Eingängen des Displays (Out A an In A, Out B an In B). Überprüfe die Ausgabe, während du die Steckbrücken in folgenden Kombinationen setzt.

Binär | Dezimal | Ausgabe
0000 | 0
0001 | 1
0010 | 2
0011 | 3
0100 | 4

Tabelle 1: Test 0 bis 4

Binär | Dezimal | Ausgabe
0101 | 5
0110 | 6
0111 | 7
1000 | 8
1001 | 9

Tabelle 2: Test 5 bis 9

3

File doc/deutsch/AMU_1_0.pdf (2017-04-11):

# Analog Multiplexer v1.0

mexdulon

8. April 2017

1

mexdulon | 1 ANALOG MULTIPLEXER

## 1 Analog Multiplexer

### 1.1 Allgemein

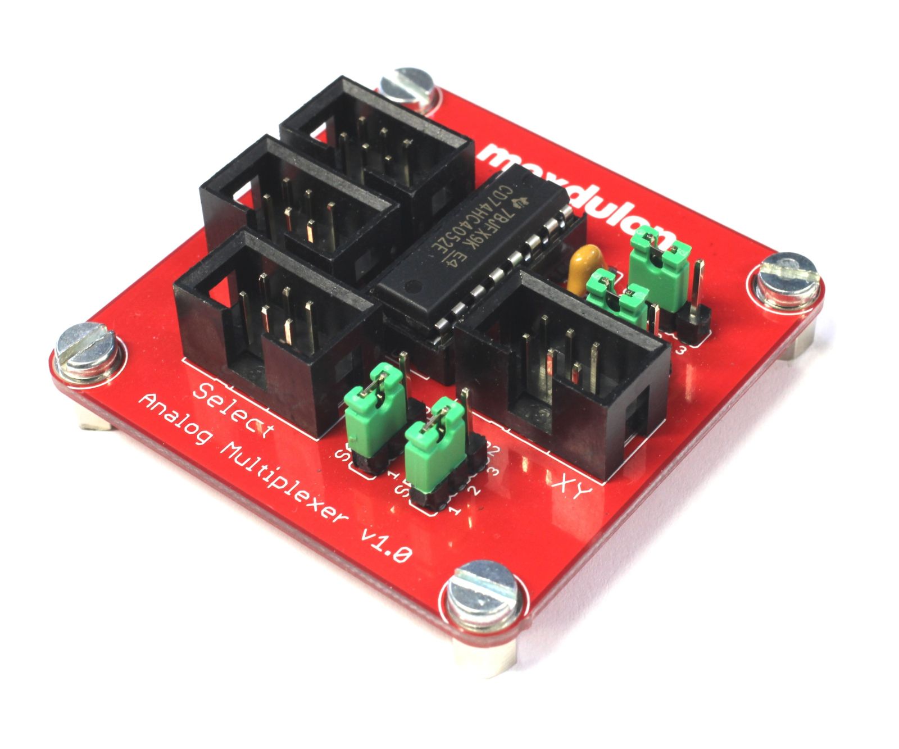
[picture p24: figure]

Der Analog Multiplexer kann Signale (digital oder analog) umschalten und verbinden.

### 1.2 Funktion

Die beiden Ports X und Y können mit dem Port XY verbunden werden. Welcher Pin des jeweiligen Ports mit welchem verbunden ist, hängt von den Jumperstellungen JP3 und JP4 sowie dem Eingang Select ab.

### 1.3 Aufbau

Kürzel | Wert | Bezeichnung
C1 | 100n | Kondensator
IC1 | 4052N | IC (Analog Mux)
JP1 | SA 0/2 | Stiftleiste 1x3
JP2 | SB 1/3 | Stiftleiste 1x3
JP3 | X 0/2 | Stiftleiste 1x3
JP4 | Y 1/3 | Stiftleiste 1x3
X1 | X | Wannenstecker
X2 | Y | Wannenstecker
X3 | XY | Wannenstecker
X4 | Select | Wannenstecker


### 1.4 Test

2

mexdulon | 1 ANALOG MULTIPLEXER


3

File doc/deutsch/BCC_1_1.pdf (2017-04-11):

# BCD Counter v1.1

mexdulon

8. April 2017

1

mexdulon | 1 BCD UP/DOWN COUNTER

## 1 BCD Up/Down Counter

### 1.1 Allgemein


Das Board BCD Up/Down Counter kann Werte (0 bis 9) hoch- und runterzählen oder entsprechende Werte laden.

### 1.2 Funktion

Das Board enthält 5 Ports, 3 davon sind für Eingaben und zwei für Ausgaben. Der Eingang In ist für Datenworte, die in den Zähler geladen werden sollen. Der Eingang Mode legt den Modus für den Zähler fest (siehe Tabelle unten) und Ctrl ist für das Taktsignal und optionales Rücksetzsignal. Der Ausgang Out ist der gewöhnliche Ausgang des Zählers. Out C/B kann benutzt werden, um mit den Bits Borrow und Carry zu arbeiten. Der Jumper JP1 sollte gewöhnlich auf 2-3 gesetzt werden, dann wird der Zähler nicht zurückgesetzt. Soll der Zähler über das Signal Ctrl-3 rücksetzbar sein, ist 1-2 die gewünschte Stellung.

Mode-3 Count Down | Mode-2 /Load | Mode-1 Count Enable | CLR | Funktion
X | X | X | H | Rücksetzen (alle Bits auf L)
X | L | X | L | Wert laden (In)
X | H | L | L | Wert bleibt stehen
L | H | H | L | Hochzählen bei Clk
H | H | H | L | Herunterzählen bei Clk
L steht für Low(0), H für High(1) und X für Signal ist nicht relevant(kann High oder Low sein). Clk meint eine Taktflanke (Wechsel von Low auf High) an Ctrl-1.

2

mexdulon | 1 BCD UP/DOWN COUNTER


### 1.3 Aufbau


Kürzel | Wert | Bezeichnung
C1 | 100n | Kondensator
C2 | 100n | Kondensator
JP1 | CLR 3/L | Stiftleiste 1x3
V1 | 74HC192N | IC (Counter)
V2 | 74HC00N | IC (NAND)
X1 | In | Wannenstecker
X2 | Mode | Wannenstecker
X3 | Ctrl | Wannenstecker
X4 | Out | Wannenstecker
X5 | Out C/B | Wannenstecker

3

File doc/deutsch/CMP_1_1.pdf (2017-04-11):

# Comparator v1.1

mexdulon

8. April 2017

1

mexdulon | 1 COMPARATOR

## 1 Comparator

### 1.1 Allgemein


Das Board Comparator vergleicht die Werte zwei binärer Datenworte miteinander und gibt das Ergbnis aus. Das Ergebnis kann A>B, A=B oder A<B sein, entsprechend ist der jeweilige Pin High.

### 1.2 Funktion

Die Datenworte der beiden Eingänge In A und In Bwerden miteinander verglichen und das Ergebnis am Ausgang Out ausgegeben. Wenn der Wert von A größer als der von B ist, ist Out-1High(1). Ist derWert B größer als A, dann ist Out-2High, sind dieWerte gleich ist Out-3 High. Die jeweils anderen Signale am Ausgang sind Low. In den meisten Fällen sollen nur die beiden 4-Bit Werte miteinander verglichen werden. Dafür werden die 3 Steckbrücken an JP4 gesetzt. Sollen größere Werte verglichen werden, können mehrere Comparatoren zusammengeschaltet und dafür der optionale Eingang In Cmp genutzt werden.
Hinweis: Der Comparator vergleicht die positiven Ganzzahlwerte, denen die Datenworte entsprechen. Wenn du vorzeichenbehaftete Zahlen vergleichen möchtest, ist dieser Comparator nicht direkt verwendbar.

2

mexdulon | 1 COMPARATOR


### 1.3 Aufbau


Kürzel | Wert | Bezeichnung
C1 | 100n | Kondensator
IC1 | 74HC85N | IC (Comparator)
JP4 | CMP STD | Stiftleiste 2x3
R1 | 10k | Widerstand
R2 | 10k | Widerstand
X1 | In A | Wannenstecker
X2 | In B | Wannenstecker
X3 | In Cmp | Wannenstecker
X4 | Out | Wannenstecker

3

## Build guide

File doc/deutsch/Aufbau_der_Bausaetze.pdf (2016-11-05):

mexdulon | Aufbau der Bausätze | 05.11.16

## Bestückung der Platinen

Überprüfe anhand der Stückliste, ob alle benötigten Bauteile im Lieferumfang enthalten sind. Danach kannst du mit der Montage beginnen. Es ist vorteilhaft, beim Bestücken mit den niedrigsten Bauteilen anzufangen. Eine empfehlenswerte Reihenfolge ist also folgende:
Widerstände, Buzzer, LEDs, IC Fassungen, Taster, Kondensatoren, Elkos, Stiftleisten, Stecker.
Zuerst wird das gewünschte Bauteil positioniert und in die Platine gesteckt. Dann wird die Platine umgedreht, um das Bauteil von der Rückseite der Platine zu löten. Manchmal kann es zweckmäßig sein, eine sogenannte „Dritte-Hand“ oder einen Platinenhalter zu verwenden, um das Bauteil an seinem Platz zu halten. Es ist jedoch auch möglich ohne solche Hilfsmittel auszukommen und die Platine auf der Tischfläche zu löten. Für Lötanfänger empfehlen wir die Einführung durch eine erfahrene Person. Auch Video Anleitungen (z.B. auf Youtube) können vor den ersten Versuchen hilfreich sein.
Nachdem alles fertig gelötet ist, können die ICs eingesetzt werden (siehe unten). Überprüfe vor dem ersten Betrieb noch einmal, ob alle Bauteile richtig eingesetzt sind und keine Kurzschlüsse (bspw. durch unerwünschte Lötbrücken) entstanden sind. Dafür kannst du auch ein Multimeter einsetzen.

Beschriftung der Bauteile
Jedes Bauteil hat einen Namen im Schaltplan und im Board-Layout. Zusätzlich haben die meisten Bauteile einen Wert, der ebenfalls auf dem Board aufgedruckt ist. Der Name setzt sich aus einem Kürzel und einer fortgeführten Nummer zusammen. Folgende Kürzel werden auf den Boards eingesetzt:
Kürzel | Bedeutung | Wert (Value)
C | Kondensator, Elko | Farad
IC | IC (integrierter Schaltkreis)
JP | Stiftleiste | Funktion
P | LED (Leuchtdiode), Display
R | Widerstand | Ohm
RN | Widerstands-Netzwerk | Ohm
S | Taster | Funktion
SG | Buzzer
V | IC (integrierter Schaltkreis)
X | Stecker, Buchse | Funktion

mexdulon | Aufbau der Bausätze | 05.11.16

Vorsätze zu Einheiten

Kürzel P | Name Peta | Zehnerpotenz 10¹⁵ | Faktor 1 000 000 000 000 000
T | Tera | 10¹² | 1 000 000 000 000
G | Giga | 10⁹ | 1 000 000 000
M | Mega | 10⁶ | 1 000 000
k m | Kilo Milli | 10³ 10⁻³ | 1 000 0,001
µ | Mikro | 10⁻⁶ | 0,000 001
n | Nano | 10⁻⁹ | 0,000 000 001
p | Pico | 10⁻¹² | 0,000 000 000 001
f | Femto | 10⁻¹⁵ | 0,000 000 000 000 001

mexdulon | Aufbau der Bausätze | 05.11.16

Abbildungen der Bauteile
Widerstand | Elektrolyt-Kondensator (Elko)
Widerstands-Netzwerk | IC Fassung
Buzzer (Summer) | IC
LED (einfarbig) | Taster
RGB LED (mehrfarbig) | Stiftleiste
7-Segment-Display | Wannenstecker
Kondensator | Pfostenleiste + Zugentlastung (für Kabel)
Jumper (Steckbrücke) | USB Buchse

mexdulon | Aufbau der Bausätze | 05.11.16

Widerstände
Bei den tetra-Board Bausätzen werden zwei grundlegende Widerstandstypen eingesetzt: Einzelne Widerstände und Widerstands-Netzwerke. Für die Identifizierung der einzelnen Widerstände werden Farbcodes verwendet (siehe unten). Hier müssen die Drähte zurecht gebogen werden, bevor sie ihren Platz auf der Platine einnehmen können. Bei den Netzwerken (wie übrigens auch bei größeren SMD Widerständen) gibt es typischerweise eine Beschriftung mit einem Code aus 3 Ziffern. Dabei geben die ersten beiden Ziffern den Wert und die dritte die Anzahl angehängter Nullen an. Somit ergibt 221 → 2|2|0 → 220 Ω oder 472 → 4|7|00 → 4700 Ω = 4,7k Ω. Netzwerke gibt es wiederum in zwei Varianten: Paralleloder Sternschaltung. Für die Sternschaltung ist die Orientierung wichtig, dafür ist bei dem Aufdruck der Platine der erste Pin markiert, der meist mit einem Punkt auf dem Bauteil markiert ist.

Farbcodes
Die einzelnen bedrahteten Widerstände werden mit Farbcodes identifiziert. Dafür werden mehrere Ringe auf den Bauteilen farblich markiert. In den Bausätzen werden Widerstände mit 5 Ringen und einer Toleranz von 1 % eingesetzt. Dort stehen die ersten 3 Ringe für den Wert und der vierte für den Multiplikator. Der letzte Ringe steht für die Toleranz, also der Bereich, den der tatsächliche Widerstandswert vom gewünschten abweichen kann. Entweder ist auf der rechten Seite neben dem letzten Ring oder zwischen dem 4. und 5. Ring ein leicht größerer Abstand. Die folgende Tabelle gibt einen Überblick über die Farben und Ringe.
| Ring 1 | Ring 2 | Ring 3 | Ring 4 | Ring 5
Farbe | Wert Ziffer | Wert Ziffer | Wert Ziffer | Faktor Nullen | Toleranz
<keine> | | | | | ± 20 %
silber | | | | | ± 10 %
gold | | | | | ± 5 %
schwarz | 0 | 0 | 0 | -
braun | 1 | 1 | 1 | 0 | ± 1 %
rot | 2 | 2 | 2 | 00 | ± 2 %
orange | 3 | 3 | 3 | 000
gelb | 4 | 4 | 4 | 0 000
grün | 5 | 5 | 5 | 00 000 | ± 0,5 %
blau | 6 | 6 | 6 | 000 000 | ± 0,25 %
lila | 7 | 7 | 7 | | ± 0,1 %
grau | 8 | 8 | 8 | | ± 0,05 %
weiß | 9 | 9 | 9

mexdulon | Aufbau der Bausätze | 05.11.16

Es gibt auch Widerstände mit 3, 4 oder 6 Ringen, dann ändert sich die Bedeutung der Ringe. Bei 3 oder 4 Ringen stehen Ringe 1 und 2 für den Wert und Ring 3 für den Faktor. Der potentielle 6. Ring steht für den sogenannten Temperatur-Koeffizienten. Die Zuordnung von Farbe und Wert bleibt immer einheitlich.
Beispiele für Farbcodes:
Ringe | Farben | Widerstandswert | Toleranz
3 | braun-schwarz-rot | 1 | 0 | 00 = 1000 Ω = 1 k Ω | ± 20 %
4 | rot-rot-braun-gold | 2 | 2 | 0 = 220 Ω | ± 5 %
5 | gelb-lila-schwarz-braun-braun | 4 | 7 | 0 | 0 = 4700 Ω = 4,7 k Ω | ± 1 %
5 | rot-rot-schwarz-rot-rot | 2 | 2 | 0 | 00 = 22000 Ω = 22 k Ω | ± 2 %

In der folgenden Tabelle sind alle bisher in den tetra-Boards eingesetzten Widerstandswerte mit den dazugehörigen Farben eingetragen. Abkürzung entspricht dabei der Beschriftung auf den Boards und im Schaltplan. Es kann sein, dass hinter dem Wert noch ein ‚R‘ angehängt ist. Beachte, dass zu dem jeweiligen Farbcode noch der letzte Ring für die Toleranz hinzukommt, z.B. braun für 1 % oder gold für 5 %. Dieser ist in der Spalte Farbcode in Klammern angegeben. Wenn du dir unsicher bist, welchen Wert ein Widerstand hat, kannst du notfalls auch mit einem Multimeter nachmessen.

Abkürzung | Wert | Farbcode (5 Ringe) | 1. | 2. | 3. | 4.
68 | 68 Ω | blau-grau-schwarz-gold (braun)
100 | 100 Ω | braun-schwarz-schwarz-schwarz (braun)
220 | 220 Ω | rot-rot-schwarz-schwarz (braun)
1k | 1000 Ω | braun-schwarz-schwarz-braun (braun)
2k2 | 2200 Ω | rot-rot-schwarz-braun (braun)
4k7 | 4700 Ω | gelb-lila-schwarz-braun (braun)
10k | 10.000 Ω | braun-schwarz-schwarz-rot (braun)
22k | 22.000 Ω | rot-rot-schwarz-rot (braun)
100k | 100.000 Ω | braun-schwarz-schwarz-orange (braun)

Dioden
Dioden sperren in eine Richtung und ermöglichen den Stromfluss nur in die andere Richtung. Daher ist es beim Bestücken entscheidend, die Ausrichtung zu beachten. Der Strom fließt nur von der Anode („Pluspol“) zur Kathode („Minuspol“). Auf den Bauteilen ist die Seite der Kathode mit einem Strich markiert.

mexdulon | Aufbau der Bausätze | 05.11.16

Buzzer
Der Buzzer (auch Summer genannt) ist ein akustischer Signalgeber, der in einem runden Gehäuse untergebracht ist. Bei dem hier verwendeten Typ gibt es keine Polung, die Ausrichtung kann daher beliebig gewählt werden.
LEDs
Leuchtdioden (kurz LEDs) haben wie gewöhnliche Dioden eine Anode und eine Kathode. Auch für sie ist daher die richtige Ausrichtung bei der Bestückung wichtig. Die Bauteile der LEDs sind so markiert, dass der Draht der Kathode kürzer ist. Außerdem haben sie auf der Seite der Kathode eine Abflachung. Die Abflachung ist auch auf dem Board-Aufdruck zu sehen. Bei den bisherigen Board ist die Ausrichtung der Kathode nach unten oder rechts. Übrigens: LEDs benötigen immer einen Vorwiderstand, der den Strom begrenzt!
RGB-LEDs
Die eingesetzten Vollfarb-Leuchtdioden (RGB-LEDs) haben vier Anschlüsse: Gemeinsame Kathode und drei Anoden für rot, grün und blau. Die Reihenfolge der Drähte ist blau, grün, Kathode, rot. Achtung: Hier ist die Abflachung rot (Anode) und nicht die Kathode! Es ist hilfreich, die Drähte der LED vor dem Einstecken in die Platine zu kürzen. Da die Drähte dicht nebeneinander liegen, muss man hier besonders aufpassen, keine Lötbrücken zu erzeugen.
ICs
Die ICs werden nicht direkt auf die Platine aufgelötet, sondern in einen Sockel eingesteckt. Das hat den Vorteil, dass die ICs bei einem Defekt einfacher ausgetauscht werden können. Außerdem werden sie so nicht der Löthitze ausgesetzt, was sie beschädigen kann. Zuerst wird also der IC-Sockel platziert und festgelötet. Achte dabei auf die richtige Orientierung, also dass die Einkerbung mit der abgebildeten übereinstimmt. Wenn das Board komplett fertig gelötet ist, kann der IC eingesetzt werden. Auch hier ist die richtige Ausrichtung der Einkerbung wichtig. Damit er auf die Fassung passt, müssen die Beine des ICs etwas nach innen gebogen werden. Dafür kann ein harter Untergrund zum Abdrücken hilfreich sein.
Kondensatoren
Ähnlich wie bei den Wiederstand-Netzwerken ist bei Kondensatoren der Wert aufgedruckt. In der Regel wird hier ein dreistelliger Code verwendet: Die ersten beiden Ziffern stehen für den Wert und die dritte für die Anzahl angehängter Nullen. Der entsprechende Wert ist dann in Pikofarad (pF). So ergibt zum Beispiel 473 → 4|7|ooo → 47000 pF = 47 nF.
Elektrolyt-Kondensatoren
Bei Elektrolyt-Kondensatoren (kurz Elkos) ist es wichtig neben dem Wert auf die richtige Polung (+/-) zu achten. Sie haben den jeweiligen Wert und die Kennzeichnung der Polarität bereits aufgedruckt. Während auf der Platine der Pluspol des Bauteils markiert ist, sind bei den Bauteilen selbst häufig die Minuspole gekennzeichnet.

mexdulon | Aufbau der Bausätze | 05.11.16

Segment-Displays
Segment-Displays sind Bauteile, die mehrere Segmente mit LEDs in einem rechteckigem Gehäuse enthalten. Es gibt zwei gängige Varianten für solche Displays: Gemeinsame Anode oder gemeinsame Kathode. Entsprechend werden die Anoden oder Kathoden der einzelnen LEDs zusammengeführt. Dieser Anschluss wird dann auf einem oder mehreren Drähten herausgeführt. Wie die LEDs benötigt auch das Display Vorwiderstände für die einzelnen Segmente. Denke beim Bestücken daran, die Ausrichtung des Bauteils einzuhalten. Das Display sollte nach unten zeigen, also der Dezimalpunkt unten rechts sein.
Stiftleisten und Stecker
Bei den Stiftleisten und Steckern kann es hilfreich sein, zuerst nur einen Draht anzulöten. So kann man das Bauteil leichter korrigieren, falls es schief sitzt. Erst wenn es gerade ausgerichtet ist, werden dann die anderen Drähte festgelötet.
Abstandsbolzen und Schrauben
Wenn das Board fertig bestückt ist, können die Abstandsbolzen an den Ecken angeschraubt werden. Diese sind dazu da, dass das Board auf dem Untergrund nicht kratzt und ohne Kurzschlussgefahr genutzt werden kann. Auch können die Boards bei Bedarf mit Magneten ausgestattet werden (zum Einsatz auf Magnetboards) oder auf einem Untergrund festgeschraubt werden.
Flachbandkabel und Pfostenleisten
Das beiliegende Kabel wird zuerst in mehrere Teile geschnitten.
Wir empfehlen unterschiedliche Längen von etwa 12, 16 und
30 cm. Da kürzere Kabel für viele Schaltungen bereits ausreichen, werden gewöhnlich weniger längere Kabel benötigt. Eine Möglichkeit für 8 Kabel (1,5 m) wäre z. B. 2 x 12 cm, 4 x 16 cm und 2 x 30 cm. Um ein Kabel zu bauen, wird das Flachbandkabel in die Öffnung der Pfostenleiste gesteckt, so dass es bündig mit dem Gehäuse abschließt. Dann kann man es leicht mit den Fingern
zusammendrücken. Für den weiteren Schritt wird ein
Schraubstock (oder ein anderes Klemmwerkzeug) benötigt. Dort

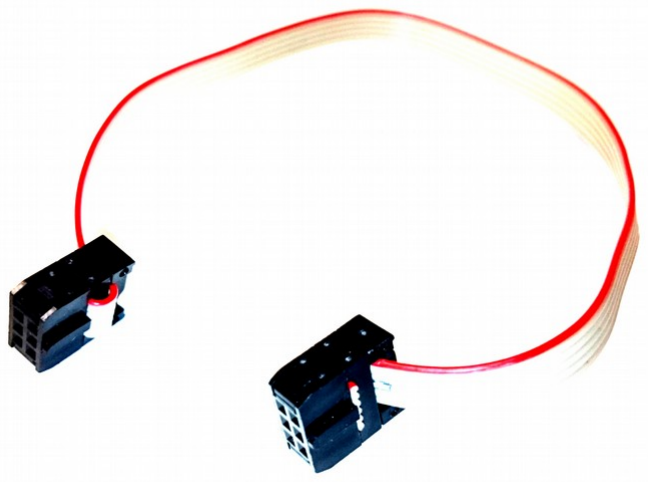
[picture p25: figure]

wird die Pfostenleiste mit Kabel eingespannt und zusammengedrückt bis es eingerastet ist. Die andere Seite des Kabels wird mit einer Pfostenleiste in gleicher Richtung bestückt (die Verbindung ist 1:1). Zum Schluss wird das Kabel an den Enden zurück gebogen und die Zugentlastungen auf die Pfostenleisten aufgesteckt und eingerastet. Das Ergebnis sollte dann der Abbildung entsprechen.
Achtung
Kontrolliere das Board noch einmal, bevor du es in Betrieb nimmst. Entferne alle Lötzinnreste und abgeschnittene Drahtenden, sodass kein Kurzschluss entstehen kann. Überprüfe, ob du die richtigen Bauteile eingesetzt hast und die Polarität bei Dioden, LEDs, Transistoren, ICs und Elkos stimmt.
Wir wünschen dir viel Spaß beim Aufbau!

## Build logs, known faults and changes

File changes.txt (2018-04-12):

SWI_1_1
-changes for better signal edges
-capacitors changed from e-caps to ceramic ones
-capacitors connected to VCC instead of GND 

CNT_1_1
-clear with fix pulldown (JP3 removed)
-JP2 connection to QD of IC1A (instead of VCC)

CLK_1_1
-connections for IC power (VDD, VSS)

LAD_1_1
-ports renamed: A0->A1, A1->A2, etc.
-identical ports: all pins are connected 1:1

SAD_1_1
-pulldown resistors for low signals
-renaming of pins (A0->A1, etc.)

RGB_1_1c
-resistor values changed: 
 -R2: 680R
 -R3: 4k7
 -R4: 470R

RGB_and_Buzzer_1.1b
-resistor values changed: 
 -R2: 4k7
 -R3: 10k
 -R4: 2k2

All boards v1.1
-bottom layer:
 -"www.mexdulon.com"
-bottom silkscreen:
 -"Licensed under CERN OHL v.1.2"

Adapter_1.1
-1 more connector for each side (A and B)
-values of connectors renamed:
 -A1 to A4 -> A
 -B1 to B4 -> B

Adder_1.1
-jumper JP3 changed:
 -2-pin -> 3-pin jumper
 -C0 L -> C0 L/H
-jumper values renamed:
 -JP1: C0 0/1 -> C0 1/2
 -JP2: C4 1/0 -> C4 2/1

AND_NAND_1.1
-copy from Logic_Gate_1.0
-values changed:
 -Out X -> AND
 -Out /X -> NAND

BCD_7SD_Decoder_1.1
-simplified:
 -X2 (Ctrl Input) removed

BCD_Counter_1.1
-X5 connections changed:
 -/Carry X5.4 -> X5.1
 -/Borrow X5.2 -> X5.2
-X5 value renamed:
 -C/B -> Out C/B

Jumper_1.1
-option for current increase for use of power bank:
 -resistor R1 added
 -JP3 (USB EN) added
-USB micro socket (X6) added

LED_Display_1.1
-jumper JP1 (EN) removed
-values renamed:
 -A -> In A and Out A
 -B -> In B and Out B

Multiplexer_1.1
-values of jumper renamed:
 -JP1: S-0/2 -> S 1/2
 -JP2: S-1/3 -> S 3/4

OR_NOR_1.1
-created from Logic_Gate_1.0
-values changed:
 -Out X -> OR
 -Out /X -> NOR

RGB_and_Buzzer_1.1
-jumper values renamed:
 -JP1: Buzz 0/1 -> Buzz 1/2
 -JP2: Buzz 2/3 -> Buzz 3/4

Universalregister_1.1
-jumper JP1, JP2, JP3, JP4 removed
-jumper JP2 (/CLR 4/H) added:
 -CLR is X2.4 or disabled
-X3 (Mode) connection changed:
 -X3.1 = SL
 -X3.2 = S0
 -X3.3 = S1
 -X3.4 = SR

XOR_NXOR_1.1
-created from Logic_Gate_1.0
-values changed:
 -Out X -> XOR
 -Out /X -> XNOR

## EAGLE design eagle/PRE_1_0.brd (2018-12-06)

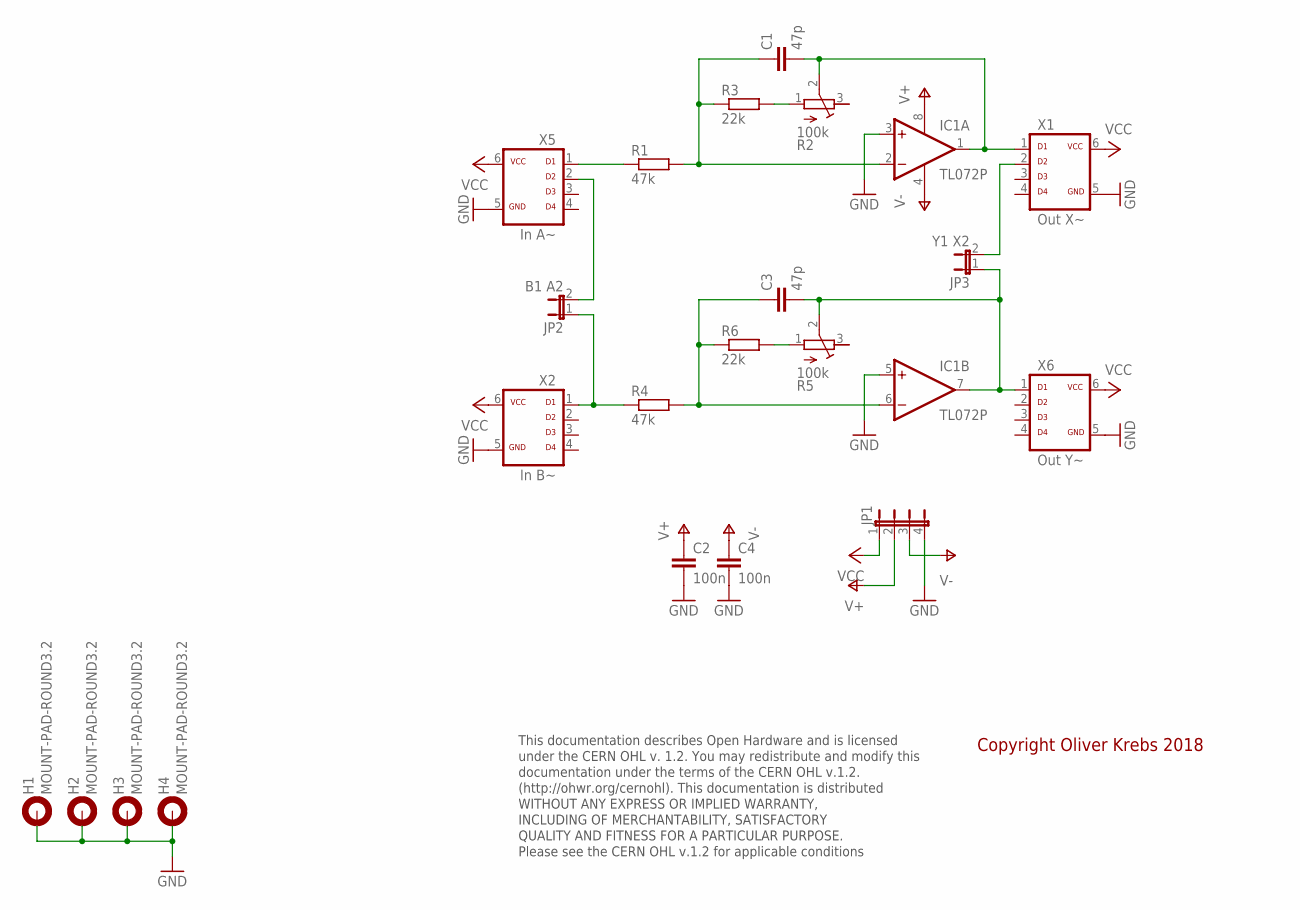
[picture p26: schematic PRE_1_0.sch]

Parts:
C1, C3: 47p; C050-025X075
C2, C4: 100n; C050-025X075
H1, H2, H3, H4: MOUNT-PAD-ROUND3.2; 3,2-PAD
IC1: TL072P; DIL08
JP1: JP4E; JP4
JP2: B1 A2; JP1
JP3: Y1 X2; JP1
R1, R4: 47k; 0207/10
R2, R5: 100k; ACP-6L
R3, R6: 22k; 0207/10
X1: Out X~; ML-6
X2: In B~; ML-6
X5: In A~; ML-6
X6: Out Y~; ML-6

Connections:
GND: C2.2, C4.2, H1.B3,2, H2.B3,2, H3.B3,2, H4.B3,2, IC1.3 (+IN), IC1.5 (+IN), JP1.4, X1.5, X2.5, X5.5, X6.5
unnamed: JP3.2, X1.2
unnamed: R5.1 (A), R6.2
unnamed: C1.2, IC1.1 (OUT), R2.2 (S), X1.1
unnamed: C3.2, IC1.7 (OUT), JP3.1, R5.2 (S), X6.1
unnamed: C1.1, IC1.2 (-IN), R1.2, R3.1
unnamed: JP2.2, X5.2
unnamed: R2.1 (A), R3.2
unnamed: C3.1, IC1.6 (-IN), R4.2, R6.1
unnamed: JP2.1, R4.1, X2.1
unnamed: R1.1, X5.1
V+: C2.1, IC1.8 (V+), JP1.2
V-: C4.1, IC1.4 (V-), JP1.3
VCC: JP1.1, X1.6, X2.6, X5.6, X6.6

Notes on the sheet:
This documentation describes Open Hardware and is licensed under the CERN OHL v. 1.2. You may redistribute and modify this documentation under the terms of the CERN OHL v.1.2. (http://ohwr.org/cernohl). This documentation is distributed WITHOUT ANY EXPRESS OR IMPLIED WARRANTY, INCLUDING OF MERCHANT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
Copyright Oliver Krebs 2018

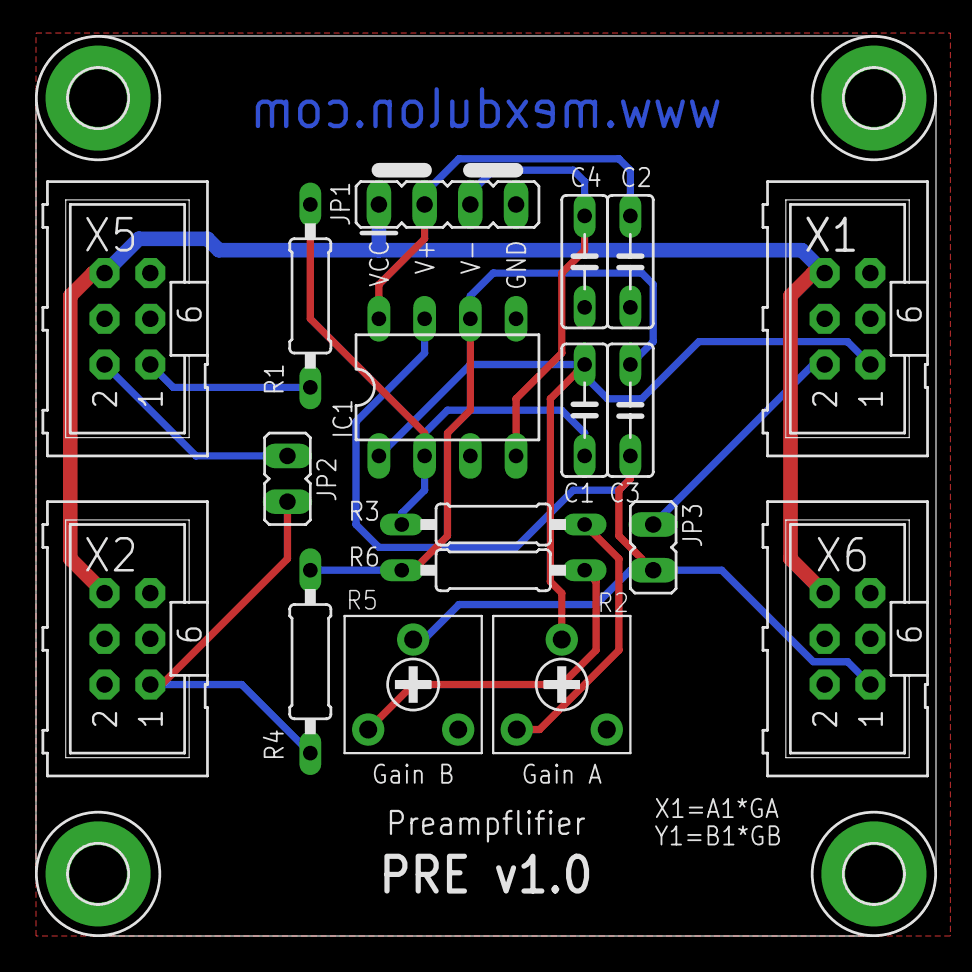
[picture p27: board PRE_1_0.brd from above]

Board: 2 copper layers, 50.0 x 50.0 mm, 22 parts (0 on the bottom side), 14 nets.

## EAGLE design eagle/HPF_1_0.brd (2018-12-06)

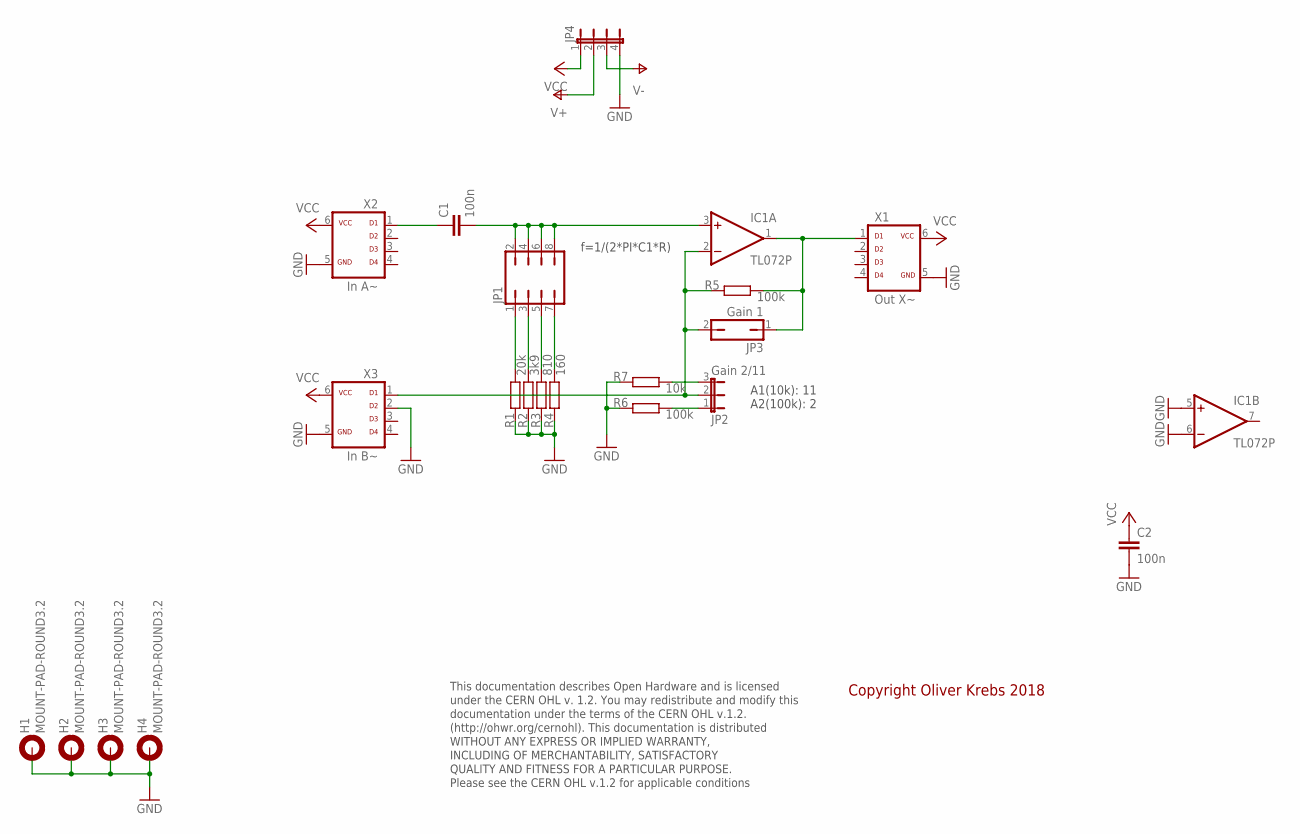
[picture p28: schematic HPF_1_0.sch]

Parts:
C1, C2: 100n; C050-025X075
H1, H2, H3, H4: MOUNT-PAD-ROUND3.2; 3,2-PAD
IC1: TL072P; DIL08
JP1: JP4Q
JP2: Gain 2/11; JP2-U
JP3: Gain 1; JP1
JP4: JP4E; JP4
R1: 20k; 0207/10
R2: 3k9; 0207/10
R3: 810; 0207/10
R4: 160; 0207/10
R5, R6: 100k; 0207/10
R7: 10k; 0207/10
X1: Out X~; ML-6
X2: In A~; ML-6
X3: In B~; ML-6

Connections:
GND: C2.2, H1.B3,2, H2.B3,2, H3.B3,2, H4.B3,2, IC1.5 (+IN), IC1.6 (-IN), JP4.4, R1.1, R2.1, R3.1, R4.1, R6.1, R7.1, X1.5, X2.5, X3.2, X3.5
unnamed: JP1.1, R1.2
unnamed: JP1.3, R2.2
unnamed: JP1.5, R3.2
unnamed: JP1.7, R4.2
unnamed: IC1.2 (-IN), JP2.2, JP3.2, R5.1, X3.1
unnamed: C1.2, IC1.3 (+IN), JP1.2, JP1.4, JP1.6, JP1.8
unnamed: C1.1, X2.1
unnamed: IC1.1 (OUT), JP3.1, R5.2, X1.1
unnamed: JP2.3, R7.2
unnamed: JP2.1, R6.2
V+: IC1.8 (V+), JP4.2
V-: IC1.4 (V-), JP4.3
VCC: C2.1, JP4.1, X1.6, X2.6, X3.6

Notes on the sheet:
This documentation describes Open Hardware and is licensed under the CERN OHL v. 1.2. You may redistribute and modify this documentation under the terms of the CERN OHL v.1.2. (http://ohwr.org/cernohl). This documentation is distributed WITHOUT ANY EXPRESS OR IMPLIED WARRANTY, INCLUDING OF MERCHANT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
Copyright Oliver Krebs 2018
A1(10k): 11 A2(100k): 2
f=1/(2*PI*C1*R)

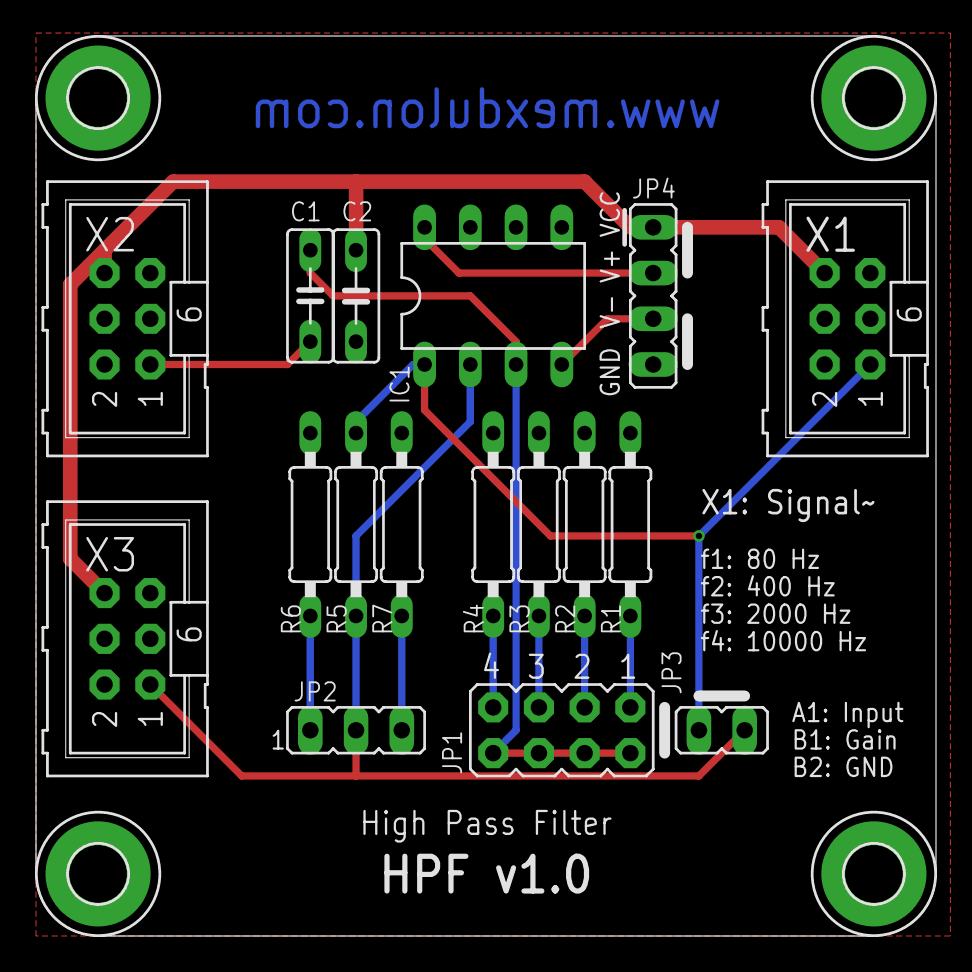
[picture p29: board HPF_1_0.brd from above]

Board: 2 copper layers, 50.0 x 50.0 mm, 21 parts (0 on the bottom side), 14 nets.

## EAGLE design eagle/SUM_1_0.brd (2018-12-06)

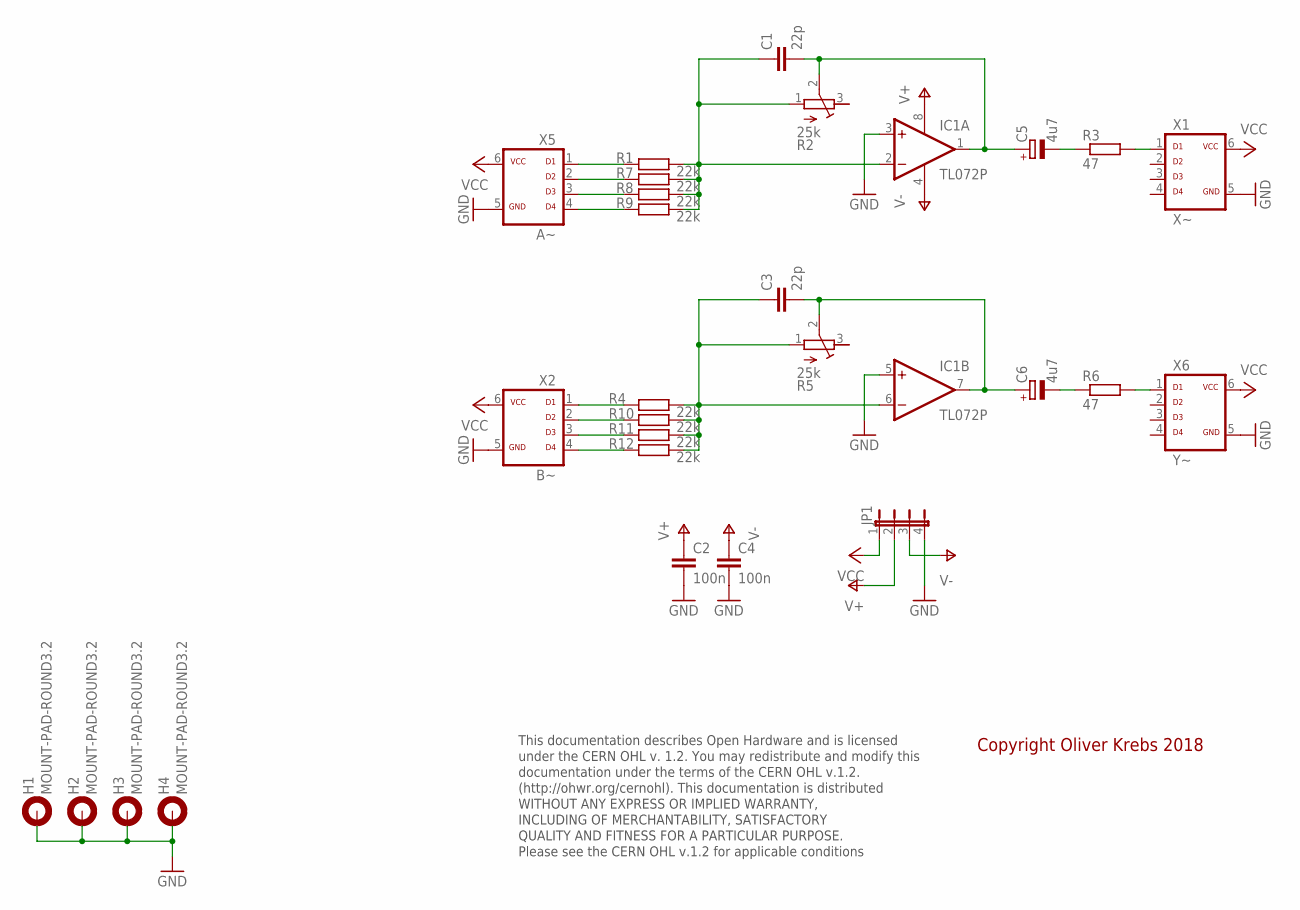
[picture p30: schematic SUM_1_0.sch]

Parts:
C1, C3: 22p; C050-025X075
C2, C4: 100n; C050-025X075
C5, C6: 4u7; E2-4
H1, H2, H3, H4: MOUNT-PAD-ROUND3.2; 3,2-PAD
IC1: TL072P; DIL08
JP1: JP4E; JP4
R1, R4, R7, R8, R9, R10, R11, R12: 22k; 0207/10
R2, R5: 25k; ACP-6L
R3, R6: 47; 0207/10
X1: X~; ML-6
X2: B~; ML-6
X5: A~; ML-6
X6: Y~; ML-6

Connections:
GND: C2.2, C4.2, H1.B3,2, H2.B3,2, H3.B3,2, H4.B3,2, IC1.3 (+IN), IC1.5 (+IN), JP1.4, X1.5, X2.5, X5.5, X6.5
unnamed: C5.-, R3.1
unnamed: R3.2, X1.1
unnamed: C1.2, C5.+, IC1.1 (OUT), R2.2 (S)
unnamed: C3.2, C6.+, IC1.7 (OUT), R5.2 (S)
unnamed: C1.1, IC1.2 (-IN), R1.2, R2.1 (A), R7.2, R8.2, R9.2
unnamed: R7.1, X5.2
unnamed: C3.1, IC1.6 (-IN), R4.2, R5.1 (A), R10.2, R11.2, R12.2
unnamed: C6.-, R6.1
unnamed: R4.1, X2.1
unnamed: R1.1, X5.1
unnamed: R8.1, X5.3
unnamed: R9.1, X5.4
unnamed: R6.2, X6.1
unnamed: R10.1, X2.2
unnamed: R11.1, X2.3
unnamed: R12.1, X2.4
V+: C2.1, IC1.8 (V+), JP1.2
V-: C4.1, IC1.4 (V-), JP1.3
VCC: JP1.1, X1.6, X2.6, X5.6, X6.6

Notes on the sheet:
This documentation describes Open Hardware and is licensed under the CERN OHL v. 1.2. You may redistribute and modify this documentation under the terms of the CERN OHL v.1.2. (http://ohwr.org/cernohl). This documentation is distributed WITHOUT ANY EXPRESS OR IMPLIED WARRANTY, INCLUDING OF MERCHANT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
Copyright Oliver Krebs 2018

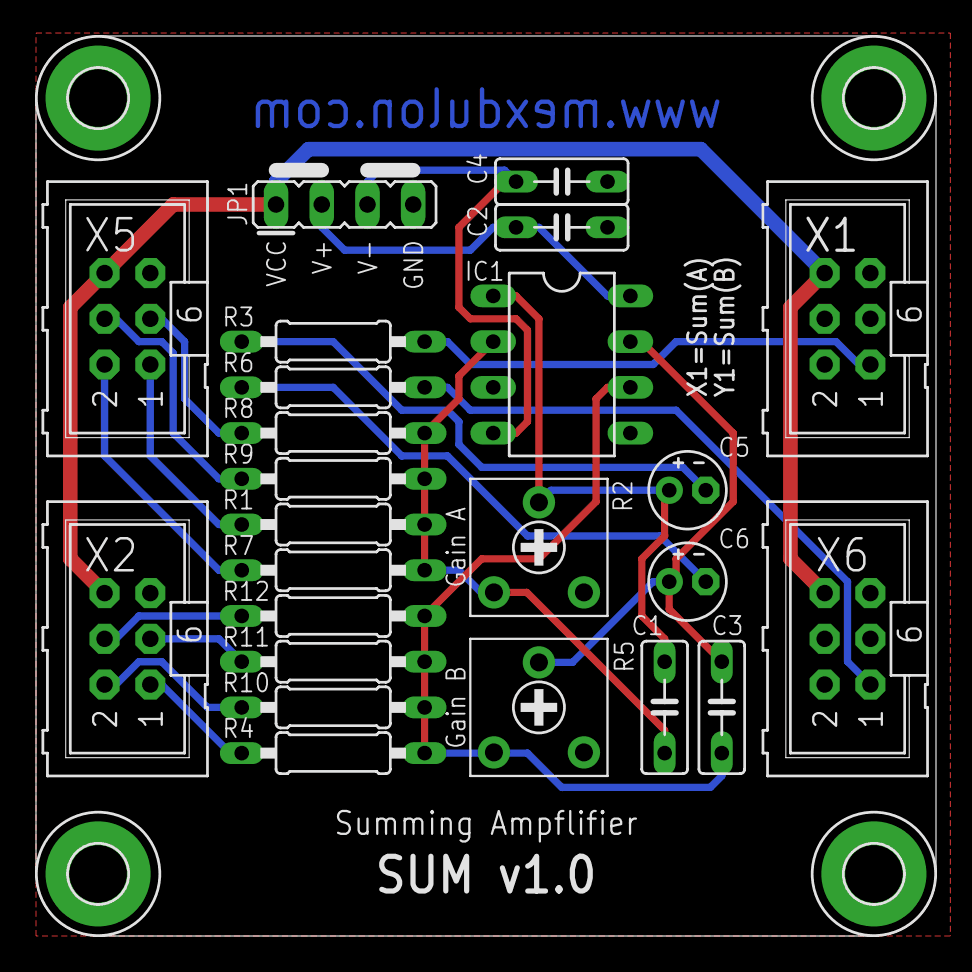
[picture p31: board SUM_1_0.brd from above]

Board: 2 copper layers, 50.0 x 50.0 mm, 28 parts (0 on the bottom side), 20 nets.

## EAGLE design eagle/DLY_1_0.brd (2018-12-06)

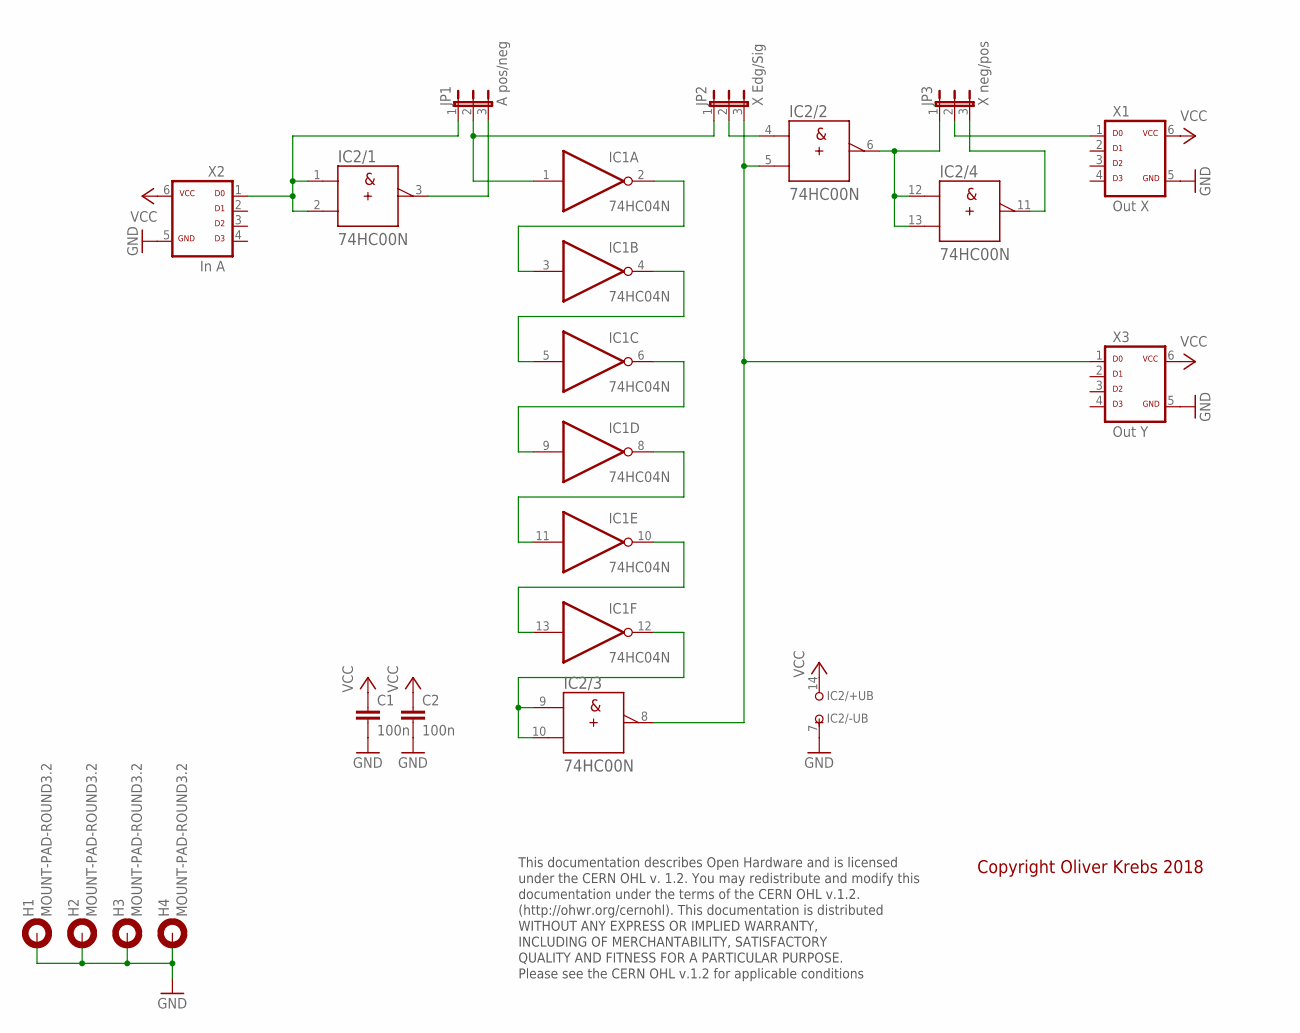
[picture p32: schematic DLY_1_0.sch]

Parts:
C1, C2: 100n; C050-025X075
H1, H2, H3, H4: MOUNT-PAD-ROUND3.2; 3,2-PAD
IC1: 74HC04N; DIL14
IC2: 74HC00N; DIL14
JP1: A pos/neg; JP2
JP2: X Edg/Sig; JP2
JP3: X neg/pos; JP2
X1: Out X; ML-6
X2: In A; ML-6
X3: Out Y; ML-6

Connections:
GND: C1.2, C2.2, H1.B3,2, H2.B3,2, H3.B3,2, H4.B3,2, IC1.7 (GND), IC2.7 (-UB), X1.5, X2.5, X3.5
unnamed: IC2.1 (A), IC2.2 (B), JP1.1, X2.1
unnamed: IC1.2 (O), IC1.3 (I)
unnamed: IC1.4 (O), IC1.5 (I)
unnamed: IC1.6 (O), IC1.9 (I)
unnamed: IC1.8 (O), IC1.11 (I)
unnamed: IC2.5 (B), IC2.8 (Y), JP2.3, X3.1
unnamed: IC2.3 (Y), JP1.3
unnamed: IC1.1 (I), JP1.2, JP2.1
unnamed: IC2.4 (A), JP2.2
unnamed: IC1.12 (O), IC2.9 (A), IC2.10 (B)
unnamed: IC2.6 (Y), IC2.12 (A), IC2.13 (B), JP3.1
unnamed: IC2.11 (Y), JP3.3
unnamed: JP3.2, X1.1
unnamed: IC1.10 (O), IC1.13 (I)
VCC: C1.1, C2.1, IC1.14 (VCC), IC2.14 (+UB), X1.6, X2.6, X3.6

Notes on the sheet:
This documentation describes Open Hardware and is licensed under the CERN OHL v. 1.2. You may redistribute and modify this documentation under the terms of the CERN OHL v.1.2. (http://ohwr.org/cernohl). This documentation is distributed WITHOUT ANY EXPRESS OR IMPLIED WARRANTY, INCLUDING OF MERCHANT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
Copyright Oliver Krebs 2018

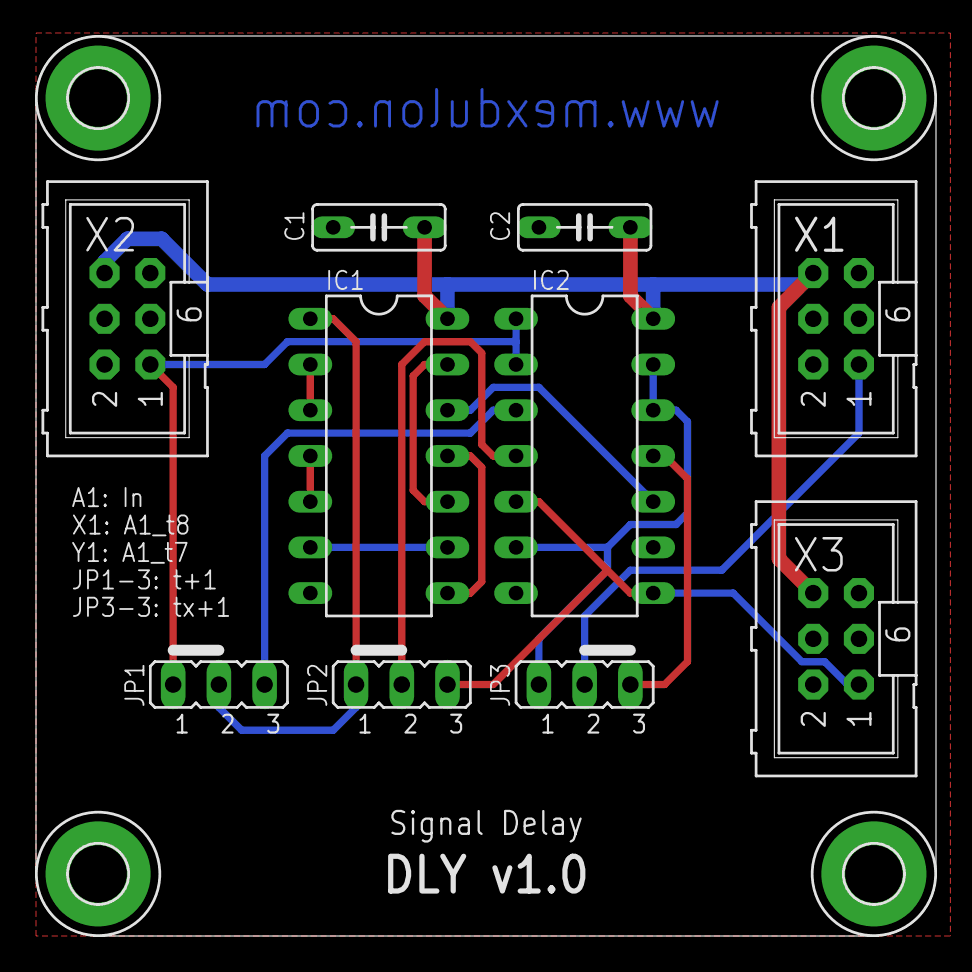
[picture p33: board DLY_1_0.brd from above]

Board: 2 copper layers, 50.0 x 50.0 mm, 14 parts (0 on the bottom side), 16 nets.

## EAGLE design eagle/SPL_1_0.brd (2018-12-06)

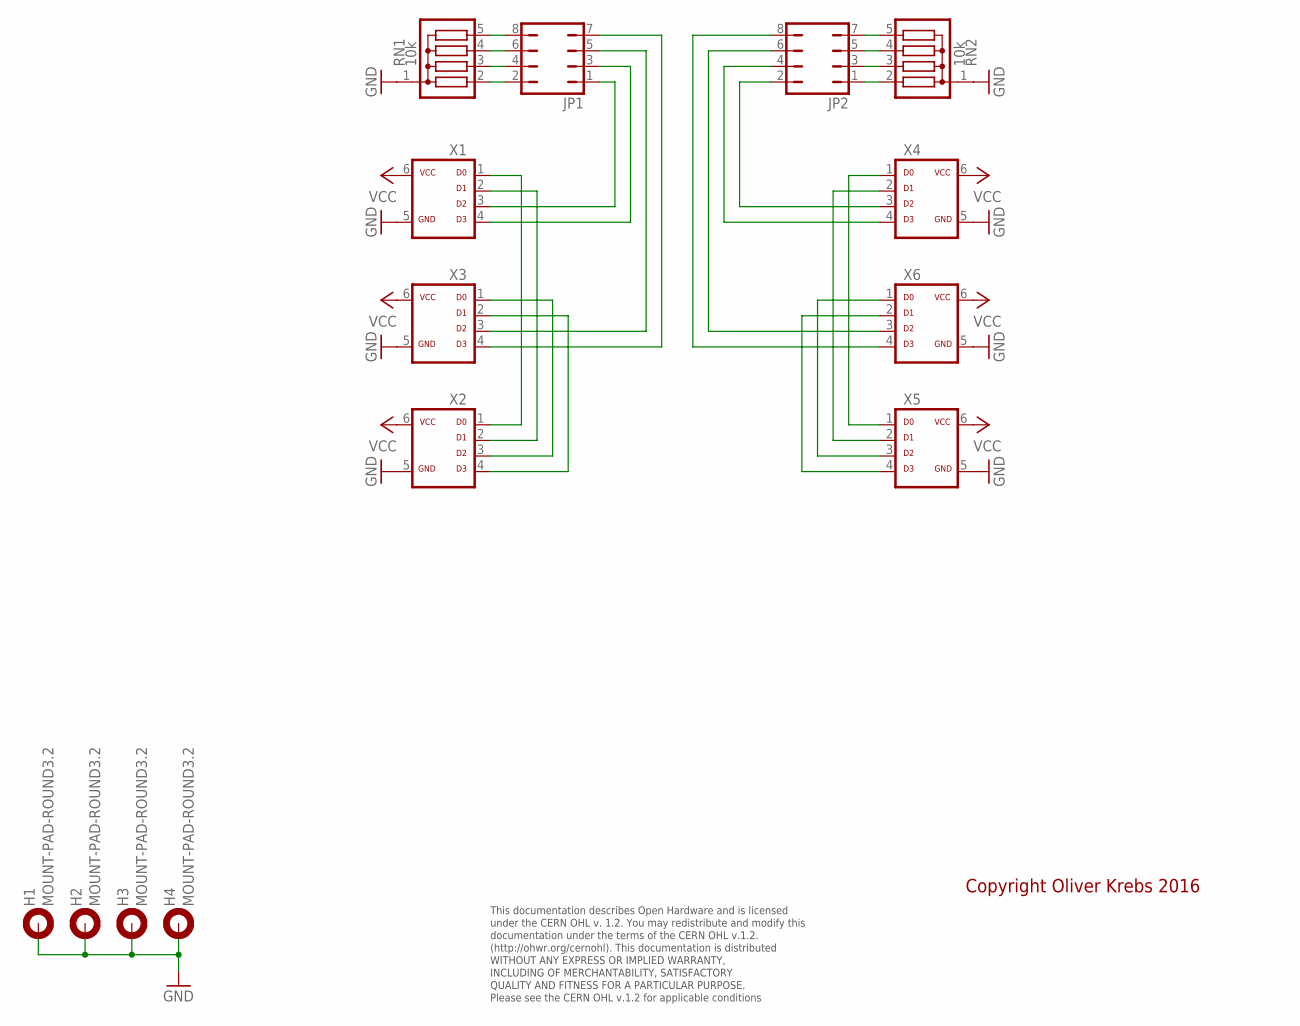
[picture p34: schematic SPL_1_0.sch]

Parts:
H1, H2, H3, H4: MOUNT-PAD-ROUND3.2; 3,2-PAD
JP1, JP2: JP4Q
RN1, RN2: 10k; SIL5
X1, X2, X3, X4, X5, X6: ML6D; ML-6

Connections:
GND: H1.B3,2, H2.B3,2, H3.B3,2, H4.B3,2, RN1.1, RN2.1, X1.5, X2.5, X3.5, X4.5, X5.5, X6.5
unnamed: X1.1, X2.1
unnamed: X1.2, X2.2
unnamed: X2.3, X3.1
unnamed: X2.4, X3.2
unnamed: X4.1, X5.1
unnamed: X4.2, X5.2
unnamed: X5.3, X6.1
unnamed: X5.4, X6.2
unnamed: JP1.2, RN1.2
unnamed: JP1.4, RN1.3
unnamed: JP1.6, RN1.4
unnamed: JP1.8, RN1.5
unnamed: JP2.1, RN2.2
unnamed: JP2.3, RN2.3
unnamed: JP2.5, RN2.4
unnamed: JP2.7, RN2.5
unnamed: JP1.1, X1.3
unnamed: JP1.3, X1.4
unnamed: JP1.5, X3.3
unnamed: JP1.7, X3.4
unnamed: JP2.8, X6.4
unnamed: JP2.6, X6.3
unnamed: JP2.4, X4.4
unnamed: JP2.2, X4.3
VCC: X1.6, X2.6, X3.6, X4.6, X5.6, X6.6

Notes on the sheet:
This documentation describes Open Hardware and is licensed under the CERN OHL v. 1.2. You may redistribute and modify this documentation under the terms of the CERN OHL v.1.2. (http://ohwr.org/cernohl). This documentation is distributed WITHOUT ANY EXPRESS OR IMPLIED WARRANTY, INCLUDING OF MERCHANT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
Copyright Oliver Krebs 2016

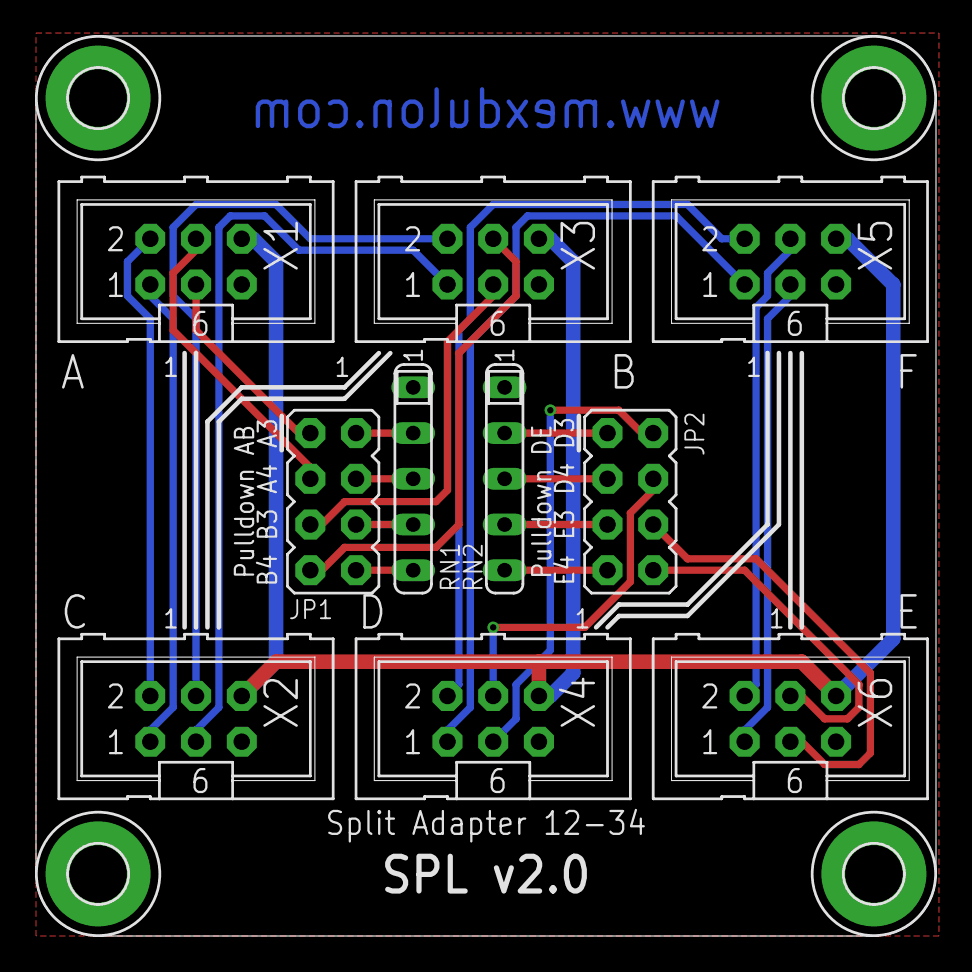
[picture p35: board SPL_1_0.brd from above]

Board: 2 copper layers, 50.0 x 50.0 mm, 14 parts (0 on the bottom side), 26 nets.

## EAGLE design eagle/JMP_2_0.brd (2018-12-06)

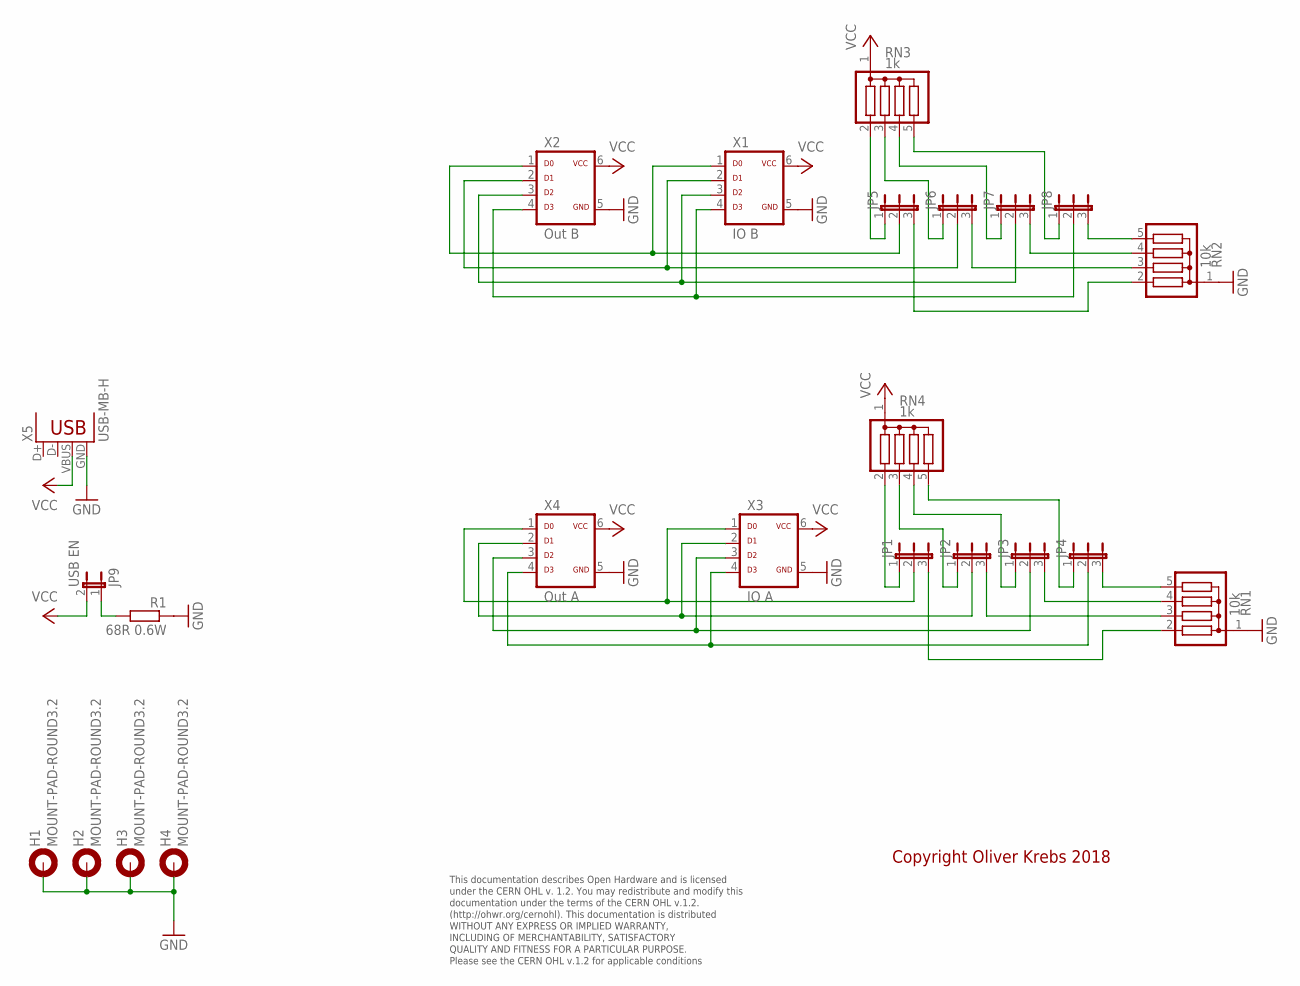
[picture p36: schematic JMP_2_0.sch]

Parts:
H1, H2, H3, H4: MOUNT-PAD-ROUND3.2; 3,2-PAD
JP1, JP2, JP3, JP4, JP5, JP6, JP7, JP8: JP2E; JP2-S
JP9: USB EN; JP1
R1: 68R 0.6W; 0207/10
RN1, RN2: 10k; SIL5
RN3, RN4: 1k; SIL5
X1: IO B; ML-6
X2: Out B; ML-6
X3: IO A; ML-6
X4: Out A; ML-6
X5: USB-MB-H

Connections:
GND: H1.B3,2, H2.B3,2, H3.B3,2, H4.B3,2, R1.1, RN1.1, RN2.1, X1.5, X2.5, X3.5, X4.5, X5.GND
unnamed: JP5.2, X1.1, X2.1
unnamed: JP6.2, X1.2, X2.2
unnamed: JP1.2, X3.1, X4.1
unnamed: JP8.2, X1.4, X2.4
unnamed: JP2.2, X3.2, X4.2
unnamed: JP4.2, X3.4, X4.4
unnamed: JP7.2, X1.3, X2.3
unnamed: JP3.2, X3.3, X4.3
unnamed: JP8.1, RN3.5
unnamed: JP9.1, R1.2
unnamed: JP5.1, RN3.2
unnamed: JP6.1, RN3.3
unnamed: JP7.1, RN3.4
unnamed: JP1.1, RN4.2
unnamed: JP2.1, RN4.3
unnamed: JP3.1, RN4.4
unnamed: JP4.1, RN4.5
unnamed: JP5.3, RN2.2
unnamed: JP6.3, RN2.3
unnamed: JP7.3, RN2.4
unnamed: JP8.3, RN2.5
unnamed: JP4.3, RN1.5
unnamed: JP3.3, RN1.4
unnamed: JP2.3, RN1.3
unnamed: JP1.3, RN1.2
VCC: JP9.2, RN3.1, RN4.1, X1.6, X2.6, X3.6, X4.6, X5.VBUS

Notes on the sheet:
This documentation describes Open Hardware and is licensed under the CERN OHL v. 1.2. You may redistribute and modify this documentation under the terms of the CERN OHL v.1.2. (http://ohwr.org/cernohl). This documentation is distributed WITHOUT ANY EXPRESS OR IMPLIED WARRANTY, INCLUDING OF MERCHANT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
Copyright Oliver Krebs 2018

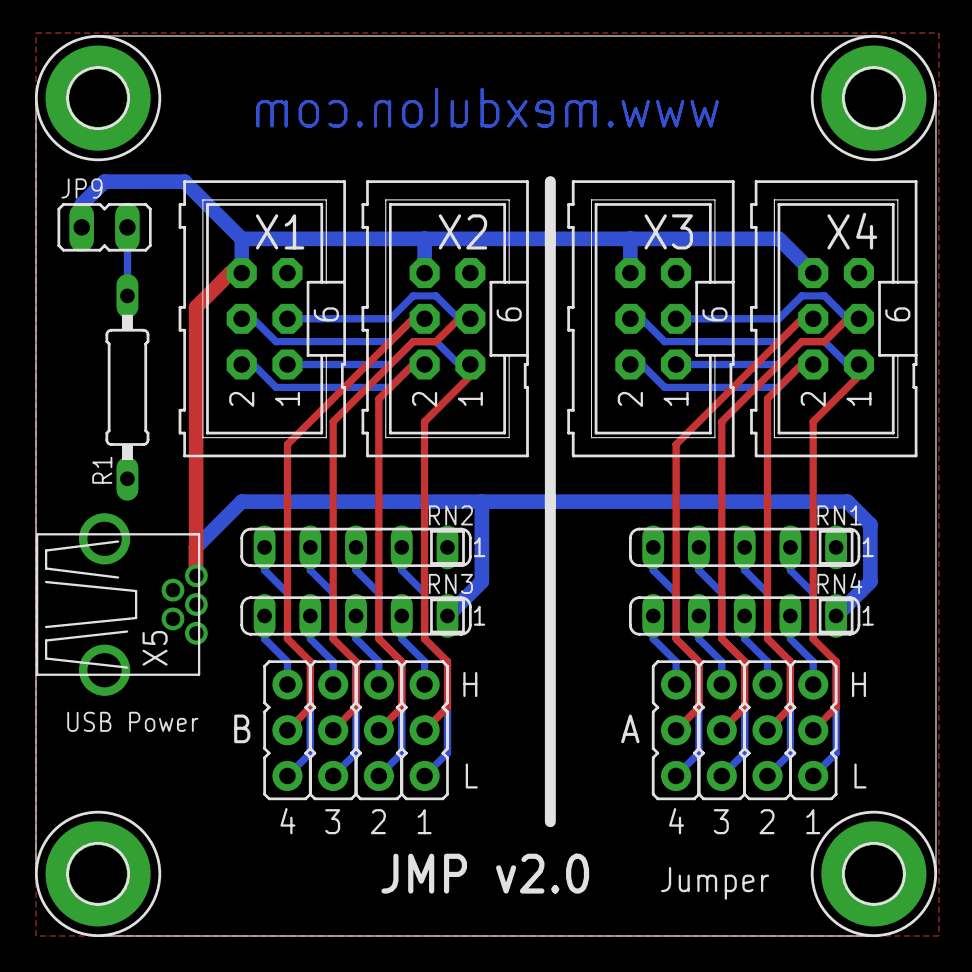
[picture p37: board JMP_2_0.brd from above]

Board: 2 copper layers, 50.0 x 50.0 mm, 23 parts (0 on the bottom side), 27 nets.

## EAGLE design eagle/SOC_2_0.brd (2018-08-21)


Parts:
H1, H2, H3, H4: MOUNT-PAD-ROUND3.2; 3,2-PAD
JP1, JP2, JP3, JP4, JP5, JP6: JP5Q
X1, X2, X3, X4, X5, X6: ML6D; ML-6

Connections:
GND: H1.B3,2, H2.B3,2, H3.B3,2, H4.B3,2, JP1.9, JP2.9, JP3.9, JP4.9, JP5.9, JP6.9, X1.5, X2.5, X3.5, X4.5, X5.5, X6.5
unnamed: JP1.1, JP1.2, X1.1
unnamed: JP1.3, JP1.4, X1.2
unnamed: JP1.5, JP1.6, X1.3
unnamed: JP1.7, JP1.8, X1.4
unnamed: JP2.1, JP2.2, X2.1
unnamed: JP2.3, JP2.4, X2.2
unnamed: JP2.5, JP2.6, X2.3
unnamed: JP2.7, JP2.8, X2.4
unnamed: JP3.1, JP3.2, X3.1
unnamed: JP3.3, JP3.4, X3.2
unnamed: JP3.5, JP3.6, X3.3
unnamed: JP3.7, JP3.8, X3.4
unnamed: JP4.1, JP4.2, X4.1
unnamed: JP4.3, JP4.4, X4.2
unnamed: JP4.5, JP4.6, X4.3
unnamed: JP4.7, JP4.8, X4.4
unnamed: JP5.1, JP5.2, X5.1
unnamed: JP5.3, JP5.4, X5.2
unnamed: JP5.5, JP5.6, X5.3
unnamed: JP5.7, JP5.8, X5.4
unnamed: JP6.1, JP6.2, X6.1
unnamed: JP6.3, JP6.4, X6.2
unnamed: JP6.5, JP6.6, X6.3
unnamed: JP6.7, JP6.8, X6.4
VCC: JP1.10, JP2.10, JP3.10, JP4.10, JP5.10, JP6.10, X1.6, X2.6, X3.6, X4.6, X5.6, X6.6

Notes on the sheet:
This documentation describes Open Hardware and is licensed under the CERN OHL v. 1.2. You may redistribute and modify this documentation under the terms of the CERN OHL v.1.2. (http://ohwr.org/cernohl). This documentation is distributed WITHOUT ANY EXPRESS OR IMPLIED WARRANTY, INCLUDING OF MERCHANT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
Copyright Oliver Krebs 2016


Board: 2 copper layers, 50.0 x 50.0 mm, 16 parts (0 on the bottom side), 26 nets.

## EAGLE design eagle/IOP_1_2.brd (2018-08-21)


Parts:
H1, H2, H3, H4: MOUNT-PAD-ROUND3.2; 3,2-PAD
JP1, JP2, JP3, JP4, JP5, JP6: M021.3MM-5.08; 1X02_BIG_5.08
JP7: M08; 1X08_ROUND
JP8: M08X2; 2X8
JP9: JP2EJP2-U; JP2-U
X1: A; ML-6
X2: B; ML-6

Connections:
GND: H1.B3,2, H2.B3,2, H3.B3,2, H4.B3,2, JP1.2, JP6.2, JP8.2, JP8.4, JP8.6, JP8.8, JP8.10, JP8.12, JP8.14, JP8.16, JP9.1, X1.5, X2.5
unnamed: JP2.2, JP7.2, X1.2
unnamed: JP2.1, JP7.1, X1.1
unnamed: JP3.1, JP7.3, X1.3
unnamed: JP3.2, JP7.4, X1.4
unnamed: JP8.1, JP8.3, JP8.5, JP8.7, JP8.9, JP8.11, JP8.13, JP8.15, JP9.2
unnamed: JP5.1, JP7.7, X2.3
unnamed: JP5.2, JP7.8, X2.4
unnamed: JP4.1, JP7.5, X2.1
unnamed: JP4.2, JP7.6, X2.2
VCC: JP1.1, JP6.1, JP9.3, X1.6, X2.6

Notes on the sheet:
This documentation describes Open Hardware and is licensed under the CERN OHL v. 1.2. You may redistribute and modify this documentation under the terms of the CERN OHL v.1.2. (http://ohwr.org/cernohl). This documentation is distributed WITHOUT ANY EXPRESS OR IMPLIED WARRANTY, INCLUDING OF MERCHANT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
Copyright Oliver Krebs 2018

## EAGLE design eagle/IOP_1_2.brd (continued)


Board: 2 copper layers, 50.0 x 50.0 mm, 15 parts (0 on the bottom side), 11 nets.

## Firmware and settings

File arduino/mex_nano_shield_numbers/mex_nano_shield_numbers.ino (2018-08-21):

#include <Wire.h>

// maximal number of displays (for multiplexing)
#define MAX_DISPLAYS 8

// significant is twos complement? else: sign bit
#define SIGNIFICANT_TWOS_COMPLEMENT 1
// exponent is twos complement? else: sign bit
#define EXPONENT_TWOS_COMPLEMENT 1

// Port A and B
#define PIN_A_1  A3
#define PIN_A_2  A2
#define PIN_A_3  A1
#define PIN_A_4  A0
#define PIN_B_1  A7
#define PIN_B_2  A6
#define PIN_B_3  A5
#define PIN_B_4  A4

// Display Pins (Output)
#define PIN_DA  8
#define PIN_DB  7
#define PIN_DC  6
#define PIN_DD  5
#define PIN_DE  4
#define PIN_DF  3
#define PIN_DG  2
#define PIN_DP  9 // Decimal Point

// Port Z
#define PIN_Z_1   10
#define PIN_Z_2   11
#define PIN_Z_3   12
#define PIN_Z_4   13

#define CHAR_SPACE  32  // character code for space
#define CHAR_MINUS  45  // character code for minus

#define SEG_A     0
#define SEG_B     1
#define SEG_C     2
#define SEG_D     3
#define SEG_E     4
#define SEG_F     5
#define SEG_G     6
#define SEG_DP    7
#define SEGMENTS  8

#define NUM_MODES 16

// mode to display
// 8: no display (disable bit)
const uint8_t MODE_TO_DISPLAY[NUM_MODES] = {
  8, 0, 1, 5, 2, 6, 3, 7, 8, 4, 1, 5, 2, 6, 3, 7
};

#define NUM_CHARS   128 // number of characters in table DISPLAY_CHARS

const uint8_t DISPLAY_CHARS[NUM_CHARS][SEGMENTS] = {
  { LOW,  LOW,  LOW,  LOW,  LOW,  LOW,  LOW,  LOW}, //   0 
  { LOW,  LOW,  LOW,  LOW,  LOW,  LOW,  LOW,  LOW}, //   1 
  { LOW,  LOW,  LOW,  LOW,  LOW,  LOW,  LOW,  LOW}, //   2 
  { LOW,  LOW,  LOW,  LOW,  LOW,  LOW,  LOW,  LOW}, //   3 
  { LOW,  LOW,  LOW,  LOW,  LOW,  LOW,  LOW,  LOW}, //   4 
  { LOW,  LOW,  LOW,  LOW,  LOW,  LOW,  LOW,  LOW}, //   5 
  { LOW,  LOW,  LOW,  LOW,  LOW,  LOW,  LOW,  LOW}, //   6 
  { LOW,  LOW,  LOW,  LOW,  LOW,  LOW,  LOW,  LOW}, //   7 
  { LOW,  LOW,  LOW,  LOW,  LOW,  LOW,  LOW,  LOW}, //   8 
  { LOW,  LOW,  LOW,  LOW,  LOW,  LOW,  LOW,  LOW}, //   9
  { LOW,  LOW,  LOW,  LOW,  LOW,  LOW,  LOW,  LOW}, //  10 
  { LOW,  LOW,  LOW,  LOW,  LOW,  LOW,  LOW,  LOW}, //  11 
  { LOW,  LOW,  LOW,  LOW,  LOW,  LOW,  LOW,  LOW}, //  12 
  { LOW,  LOW,  LOW,  LOW,  LOW,  LOW,  LOW,  LOW}, //  13 
  { LOW,  LOW,  LOW,  LOW,  LOW,  LOW,  LOW,  LOW}, //  14 
  { LOW,  LOW,  LOW,  LOW,  LOW,  LOW,  LOW,  LOW}, //  15 
  { LOW,  LOW,  LOW,  LOW,  LOW,  LOW,  LOW,  LOW}, //  16 
  { LOW,  LOW,  LOW,  LOW,  LOW,  LOW,  LOW,  LOW}, //  17 
  { LOW,  LOW,  LOW,  LOW,  LOW,  LOW,  LOW,  LOW}, //  18 
  { LOW,  LOW,  LOW,  LOW,  LOW,  LOW,  LOW,  LOW}, //  19
  { LOW,  LOW,  LOW,  LOW,  LOW,  LOW,  LOW,  LOW}, //  20 
  { LOW,  LOW,  LOW,  LOW,  LOW,  LOW,  LOW,  LOW}, //  21 
  { LOW,  LOW,  LOW,  LOW,  LOW,  LOW,  LOW,  LOW}, //  22 
  { LOW,  LOW,  LOW,  LOW,  LOW,  LOW,  LOW,  LOW}, //  23 
  { LOW,  LOW,  LOW,  LOW,  LOW,  LOW,  LOW,  LOW}, //  24 
  { LOW,  LOW,  LOW,  LOW,  LOW,  LOW,  LOW,  LOW}, //  25 
  { LOW,  LOW,  LOW,  LOW,  LOW,  LOW,  LOW,  LOW}, //  26 
  { LOW,  LOW,  LOW,  LOW,  LOW,  LOW,  LOW,  LOW}, //  27 
  { LOW,  LOW,  LOW,  LOW,  LOW,  LOW,  LOW,  LOW}, //  28 
  { LOW,  LOW,  LOW,  LOW,  LOW,  LOW,  LOW,  LOW}, //  29 
  { LOW,  LOW,  LOW,  LOW,  LOW,  LOW,  LOW,  LOW}, //  30 
  { LOW,  LOW,  LOW,  LOW,  LOW,  LOW,  LOW,  LOW}, //  31 
  { LOW,  LOW,  LOW,  LOW,  LOW,  LOW,  LOW,  LOW}, //  32  (Space)
  { LOW, HIGH,  LOW,  LOW,  LOW,  LOW,  LOW, HIGH}, //  33  !
  { LOW, HIGH,  LOW,  LOW,  LOW, HIGH,  LOW,  LOW}, //  34  "
  { LOW, HIGH, HIGH, HIGH, HIGH, HIGH, HIGH,  LOW}, //  35  #
  {HIGH,  LOW, HIGH, HIGH,  LOW, HIGH, HIGH, HIGH}, //  36  $
  { LOW,  LOW, HIGH,  LOW,  LOW, HIGH,  LOW,  LOW}, //  37  %
  {HIGH,  LOW, HIGH, HIGH, HIGH, HIGH, HIGH, HIGH}, //  38  &
  { LOW, HIGH,  LOW,  LOW,  LOW,  LOW,  LOW,  LOW}, //  39  '
  { LOW, HIGH, HIGH,  LOW,  LOW,  LOW,  LOW,  LOW}, //  40  (
  { LOW,  LOW,  LOW,  LOW, HIGH, HIGH,  LOW,  LOW}, //  41  )
  { LOW,  LOW,  LOW,  LOW,  LOW,  LOW, HIGH, HIGH}, //  42  *
  { LOW, HIGH,  LOW,  LOW,  LOW,  LOW, HIGH, HIGH}, //  43  +
  { LOW,  LOW, HIGH,  LOW,  LOW,  LOW,  LOW,  LOW}, //  44  ,
  { LOW,  LOW,  LOW,  LOW,  LOW,  LOW, HIGH,  LOW}, //  45  -
  { LOW,  LOW,  LOW,  LOW,  LOW,  LOW,  LOW, HIGH}, //  46  .
  { LOW, HIGH,  LOW,  LOW, HIGH,  LOW, HIGH,  LOW}, //  47  /
  {HIGH, HIGH, HIGH, HIGH, HIGH, HIGH,  LOW,  LOW}, //  48  0
  { LOW, HIGH, HIGH,  LOW,  LOW,  LOW,  LOW,  LOW}, //  49  1
  {HIGH, HIGH,  LOW, HIGH, HIGH,  LOW, HIGH,  LOW}, //  50  2
  {HIGH, HIGH, HIGH, HIGH,  LOW,  LOW, HIGH,  LOW}, //  51  3
  { LOW, HIGH, HIGH,  LOW,  LOW, HIGH, HIGH,  LOW}, //  52  4
  {HIGH,  LOW, HIGH, HIGH,  LOW, HIGH, HIGH,  LOW}, //  53  5
  {HIGH,  LOW, HIGH, HIGH, HIGH, HIGH, HIGH,  LOW}, //  54  6
  {HIGH, HIGH, HIGH,  LOW,  LOW,  LOW,  LOW,  LOW}, //  55  7
  {HIGH, HIGH, HIGH, HIGH, HIGH, HIGH, HIGH,  LOW}, //  56  8
  {HIGH, HIGH, HIGH, HIGH,  LOW, HIGH, HIGH,  LOW}, //  57  9
  { LOW,  LOW, HIGH,  LOW,  LOW,  LOW,  LOW,  LOW}, //  58  :
  { LOW,  LOW, HIGH,  LOW,  LOW,  LOW,  LOW, HIGH}, //  59  ;
  { LOW,  LOW,  LOW, HIGH, HIGH,  LOW, HIGH,  LOW}, //  60  <
  { LOW,  LOW,  LOW, HIGH,  LOW,  LOW, HIGH,  LOW}, //  61  =
  { LOW,  LOW, HIGH, HIGH,  LOW,  LOW, HIGH,  LOW}, //  62  >
  {HIGH, HIGH,  LOW,  LOW, HIGH,  LOW, HIGH,  LOW}, //  63  ?
  {HIGH, HIGH, HIGH, HIGH, HIGH,  LOW, HIGH, HIGH}, //  64  @
  {HIGH, HIGH, HIGH,  LOW, HIGH, HIGH, HIGH,  LOW}, //  65  A
  { LOW,  LOW, HIGH, HIGH, HIGH, HIGH, HIGH,  LOW}, //  66  B (b)
  {HIGH,  LOW,  LOW, HIGH, HIGH, HIGH,  LOW,  LOW}, //  67  C
  { LOW, HIGH, HIGH, HIGH, HIGH,  LOW, HIGH,  LOW}, //  68  D (d)
  {HIGH,  LOW,  LOW, HIGH, HIGH, HIGH, HIGH,  LOW}, //  69  E
  {HIGH,  LOW,  LOW,  LOW, HIGH, HIGH, HIGH,  LOW}, //  70  F
  {HIGH,  LOW, HIGH, HIGH, HIGH, HIGH,  LOW,  LOW}, //  71  G
  { LOW, HIGH, HIGH,  LOW, HIGH, HIGH, HIGH,  LOW}, //  72  H
  { LOW, HIGH, HIGH,  LOW,  LOW,  LOW,  LOW,  LOW}, //  73  I
  {HIGH, HIGH, HIGH, HIGH, HIGH,  LOW,  LOW,  LOW}, //  74  J
  { LOW,  LOW,  LOW,  LOW, HIGH, HIGH, HIGH, HIGH}, //  75  K
  { LOW,  LOW,  LOW, HIGH, HIGH, HIGH,  LOW,  LOW}, //  76  L
  {HIGH, HIGH, HIGH,  LOW, HIGH, HIGH,  LOW, HIGH}, //  77  M
  {HIGH, HIGH, HIGH,  LOW, HIGH, HIGH,  LOW,  LOW}, //  78  N
  {HIGH, HIGH, HIGH, HIGH, HIGH, HIGH,  LOW,  LOW}, //  79  O
  {HIGH, HIGH,  LOW,  LOW, HIGH, HIGH, HIGH,  LOW}, //  80  P
  {HIGH, HIGH, HIGH, HIGH, HIGH, HIGH,  LOW, HIGH}, //  81  Q
  {HIGH, HIGH, HIGH,  LOW, HIGH, HIGH, HIGH, HIGH}, //  82  R
  {HIGH,  LOW, HIGH, HIGH,  LOW, HIGH, HIGH,  LOW}, //  83  S
  {HIGH,  LOW,  LOW,  LOW, HIGH, HIGH,  LOW,  LOW}, //  84  T
  { LOW, HIGH, HIGH, HIGH, HIGH, HIGH,  LOW,  LOW}, //  85  U
  { LOW, HIGH,  LOW,  LOW, HIGH, HIGH, HIGH,  LOW}, //  86  V
  { LOW, HIGH, HIGH, HIGH, HIGH, HIGH,  LOW, HIGH}, //  87  W
  { LOW,  LOW,  LOW,  LOW,  LOW,  LOW,  LOW, HIGH}, //  88  X
  { LOW, HIGH, HIGH, HIGH,  LOW, HIGH, HIGH,  LOW}, //  89  Y
  {HIGH, HIGH,  LOW, HIGH, HIGH,  LOW, HIGH,  LOW}, //  90  Z
  {HIGH,  LOW,  LOW, HIGH, HIGH, HIGH,  LOW,  LOW}, //  91  [
  { LOW,  LOW, HIGH,  LOW,  LOW, HIGH, HIGH,  LOW}, //  92  backslash
  {HIGH, HIGH, HIGH, HIGH,  LOW,  LOW,  LOW,  LOW}, //  93  ]
  {HIGH,  LOW,  LOW,  LOW,  LOW,  LOW,  LOW,  LOW}, //  94  ^
  { LOW,  LOW,  LOW, HIGH,  LOW,  LOW,  LOW,  LOW}, //  95  _
  { LOW,  LOW,  LOW,  LOW,  LOW, HIGH,  LOW,  LOW}, //  96  `
  {HIGH, HIGH, HIGH, HIGH, HIGH,  LOW, HIGH,  LOW}, //  97  a
  { LOW,  LOW, HIGH, HIGH, HIGH, HIGH, HIGH,  LOW}, //  98  b
  { LOW,  LOW,  LOW, HIGH, HIGH,  LOW, HIGH,  LOW}, //  99  c
  { LOW, HIGH, HIGH, HIGH, HIGH,  LOW, HIGH,  LOW}, // 100  d
  {HIGH, HIGH,  LOW, HIGH, HIGH, HIGH, HIGH,  LOW}, // 101  e
  {HIGH,  LOW,  LOW,  LOW, HIGH, HIGH, HIGH,  LOW}, // 102  f
  {HIGH, HIGH, HIGH, HIGH,  LOW, HIGH, HIGH,  LOW}, // 103  g
  { LOW,  LOW, HIGH,  LOW, HIGH, HIGH, HIGH,  LOW}, // 104  h
  { LOW,  LOW,  LOW,  LOW, HIGH,  LOW,  LOW,  LOW}, // 105  i
  { LOW,  LOW, HIGH, HIGH,  LOW,  LOW,  LOW,  LOW}, // 106  j
  { LOW,  LOW,  LOW,  LOW, HIGH, HIGH, HIGH, HIGH}, // 107  k
  { LOW,  LOW,  LOW,  LOW, HIGH, HIGH,  LOW,  LOW}, // 108  l
  { LOW,  LOW, HIGH,  LOW, HIGH,  LOW, HIGH, HIGH}, // 109  m
  { LOW,  LOW, HIGH,  LOW, HIGH,  LOW, HIGH,  LOW}, // 110  n
  { LOW,  LOW, HIGH, HIGH, HIGH,  LOW, HIGH,  LOW}, // 111  o
  {HIGH, HIGH,  LOW,  LOW, HIGH, HIGH, HIGH,  LOW}, // 112  p
  {HIGH, HIGH, HIGH,  LOW,  LOW, HIGH, HIGH,  LOW}, // 113  q
  { LOW,  LOW,  LOW,  LOW, HIGH,  LOW, HIGH,  LOW}, // 114  r
  {HIGH,  LOW, HIGH, HIGH,  LOW, HIGH, HIGH,  LOW}, // 115  s
  { LOW,  LOW,  LOW, HIGH, HIGH, HIGH, HIGH,  LOW}, // 116  t
  { LOW,  LOW, HIGH, HIGH, HIGH,  LOW,  LOW,  LOW}, // 117  u
  { LOW,  LOW,  LOW,  LOW, HIGH,  LOW,  LOW,  LOW}, // 118  v
  { LOW,  LOW, HIGH, HIGH, HIGH,  LOW,  LOW, HIGH}, // 119  w
  { LOW, HIGH, HIGH,  LOW, HIGH, HIGH, HIGH, HIGH}, // 120  x
  { LOW, HIGH, HIGH, HIGH,  LOW, HIGH, HIGH,  LOW}, // 121  y
  {HIGH, HIGH,  LOW, HIGH, HIGH,  LOW, HIGH,  LOW}, // 122  z
  { LOW, HIGH, HIGH,  LOW,  LOW,  LOW, HIGH,  LOW}, // 123  {
  { LOW,  LOW,  LOW,  LOW, HIGH, HIGH,  LOW,  LOW}, // 124  |
  { LOW,  LOW,  LOW,  LOW, HIGH, HIGH, HIGH,  LOW}, // 125  }
  { LOW,  LOW,  LOW,  LOW,  LOW,  LOW, HIGH, HIGH}, // 126  ~
  { LOW,  LOW,  LOW,  LOW,  LOW,  LOW,  LOW,  LOW}  // 127  DEL
};

#define DIGIT_OFFSET      48 // offset for digits (starting at 0)
#define ALPHA_OFFSET      65 // offset for letters (starting at A)

uint8_t data_mode = 0;
uint8_t data_value = 0;

uint8_t segments[MAX_DISPLAYS][SEGMENTS];

uint8_t input_a = 0;
uint8_t input_b = 0;

uint8_t loopCnt = 0;
uint8_t counter = 0;

uint8_t multiplex_display = 0;

uint32_t pow2(int times)
{
  uint32_t result = 1;
  if (times > 0) {
    result = ((uint32_t)2 << (times - 1));
  }
  return result;
}

uint32_t pow10(int times)
{
  uint32_t result = 1;
  for( int i = 0; i < times; ++i) {
    result *= 10;
  } 
  return result;
}

void updateDisplay(uint8_t index) 
{
  if (index >= MAX_DISPLAYS) {
    return;
  }
  digitalWrite(PIN_DA, segments[index][0]);
  digitalWrite(PIN_DB, segments[index][1]);
  digitalWrite(PIN_DC, segments[index][2]);
  digitalWrite(PIN_DD, segments[index][3]);
  digitalWrite(PIN_DE, segments[index][4]);
  digitalWrite(PIN_DF, segments[index][5]);
  digitalWrite(PIN_DG, segments[index][6]);
  digitalWrite(PIN_DP, segments[index][7]);
}

void setDP(uint8_t index, uint8_t set)
{
  if (index >= MAX_DISPLAYS) {
    return;
  }
  segments[index][7] = set;
}

void setExpSeperator(uint8_t index)
{
  if (index >= MAX_DISPLAYS) {
    return;
  }
  segments[index][0] = HIGH;
  segments[index][1] = HIGH;
  segments[index][2] = LOW;
  segments[index][3] = LOW;
  segments[index][4] = LOW;
  segments[index][5] = HIGH;
  segments[index][6] = LOW;
  segments[index][7] = LOW;
}

void setMultSeperator(uint8_t index)
{
  if (index >= MAX_DISPLAYS) {
    return;
  }
  segments[index][0] = LOW;
  segments[index][1] = LOW;
  segments[index][2] = HIGH;
  segments[index][3] = HIGH;
  segments[index][4] = HIGH;
  segments[index][5] = LOW;
  segments[index][6] = HIGH;
  segments[index][7] = LOW;
}

void setChar(uint8_t index, uint8_t ch)
{
  if(index >= MAX_DISPLAYS || ch >= NUM_CHARS) {
    return;
  }
  for( uint8_t i = 0; i < SEGMENTS; ++i) {
    segments[index][i] = DISPLAY_CHARS[ch][i];
  } 
}

void setDigit(uint8_t index, uint8_t val)
{
  if(val <= 9) {
    setChar(index, val + DIGIT_OFFSET);
  } else {
    val -= 10;
    setChar(index, val + ALPHA_OFFSET);
  }
}

void showSpaces()
{
  for (uint8_t i = 0; i < MAX_DISPLAYS; ++i) {
    setChar(i, CHAR_SPACE);
  }
}

void showOctal(uint8_t val)
{
  setChar(0, CHAR_SPACE);
  setChar(1, CHAR_SPACE);
  setChar(2, CHAR_SPACE);
  setChar(3, CHAR_SPACE);
  setChar(4, CHAR_SPACE);
  setDigit(5, (val >> 6) & 7);
  setDigit(6, (val >> 3) & 7);
  setDigit(7, val & 7);
}

void showHexadecimal(uint8_t val)
{
  setChar(0, CHAR_SPACE);
  setChar(1, CHAR_SPACE);
  setChar(2, CHAR_SPACE);
  setChar(3, CHAR_SPACE);
  setChar(4, CHAR_SPACE);
  setChar(5, CHAR_SPACE);
  setDigit(6, (val >> 4) & 0xF);
  setDigit(7, val & 0xF);
}

void showUnsigned(uint8_t val)
{
  uint8_t hundreds = (val / 100) % 10;
  uint8_t tens = (val / 10) % 10;
  uint8_t units = val % 10;
  setChar(0, CHAR_SPACE);
  setChar(1, CHAR_SPACE);
  setChar(2, CHAR_SPACE);
  setChar(3, CHAR_SPACE);
  setChar(4, CHAR_SPACE);
  if (hundreds > 0) {
    setDigit(5, hundreds);
  } else {
    setChar(5, CHAR_SPACE);
  }
  if (tens > 0 || hundreds > 0) {
    setDigit(6, tens);
  }
  else {
    setChar(6, CHAR_SPACE);
  }
  setDigit(7, units);
}

void showTwosComplement(uint8_t val)
{
  if(val & 128) {
    val = ~(val - 1);
    showUnsigned(val);
    //setChar(4, CHAR_MINUS);
  } else {
    showUnsigned(val);
  }
}

void showSigned(uint8_t val)
{
  if(val & 128) {
    val -= 128;
    showUnsigned(val);
    setChar(4, CHAR_MINUS);
  } else {
    showUnsigned(val);
  }
}

void setDecimals(uint8_t val)
{
  uint8_t dec1 = 0;
  uint8_t dec2 = 0;
  uint8_t dec3 = 0;
  uint8_t dec4 = 0;
  if (val & 8) {
    dec1 += 5;
  }
  if (val & 4) {
    dec1 += 2;
    dec2 += 5;
  }
  if (val & 2) {
    dec1 += 1;
    dec2 += 2;
    dec3 += 5;
  }
  if (val & 1) {
    dec2 += 6;
    dec3 += 2;
    dec4 += 5;
  }
  if (dec2 > 9) {
    dec2 -= 10;
    dec1 += 1;
  }
  setDigit(4, dec1);
  setDigit(5, dec2);
  setDigit(6, dec3);
  setDigit(7, dec4);
}

void showFXU(uint8_t val)
{
  uint8_t part1 = val & 0xF;
  uint8_t part2 = (val >> 4) & 0xF;
  uint8_t tens = (part2 / 10) % 10;
  uint8_t units = part2 % 10;

  setChar(0, CHAR_SPACE);
  setChar(1, CHAR_SPACE);
  if (tens > 0) {
    setDigit(2, tens);
  } else {
    setChar(2, CHAR_SPACE);
  }
  setDigit(3, units);
  setDP(3, 1);
  setDecimals(part1);
}

void showFXS(uint8_t val)
{    
  if(val & 128) {
    val -= 128;
    showFXU(val);
    setChar(2, CHAR_MINUS);
  } else {
    showFXU(val);
    setChar(2, CHAR_SPACE);
  }
}

void showFXS_TwosComplement(uint8_t val)
{
  if(val & 128) {
    val = ~(val - 1);
    showFXU(val);
    //setChar(2, CHAR_MINUS);
  } else {
    showFXU(val);
  }
}

void showFLU(uint8_t val)
{
  uint8_t exponent = val & 0xF;
  uint8_t significant = (val >> 4) & 0xF;
  uint8_t tens = (significant / 10) % 10;
  uint8_t units = significant % 10;
  uint8_t exp10 = (exponent / 10) % 10;
  uint8_t exp1  = exponent % 10;
  
  setChar(0, CHAR_SPACE);
  if (tens > 0) {
    setDigit(1, tens);
  } else {
    setChar(1, CHAR_SPACE);
  }
  setDigit(2, units);
  setMultSeperator(3);
  setDigit(4, 2);
  setExpSeperator(5);
  setDigit(6, exp10);
  setDigit(7, exp1);
}

void showFLS(uint8_t val)
{
  uint8_t exponent = val & 0xF;
  uint8_t significant = (val >> 4) & 0xF;

  setChar(0, CHAR_SPACE);
  if (significant & 8) {
    if (SIGNIFICANT_TWOS_COMPLEMENT) {
      significant = (~significant & 0xF) + 1;
    } else {
      significant -= 8;
    }
    setChar(1, CHAR_MINUS);
  } else {
    setChar(1, CHAR_SPACE);
  }
  setDigit(2, significant);
  setMultSeperator(3);
  setDigit(4, 2);
  setExpSeperator(5);
  if (exponent & 8) {
    if (EXPONENT_TWOS_COMPLEMENT) {
      exponent = (~exponent & 0xF) + 1;
    } else {
      exponent -= 8;
    }
    setChar(6, CHAR_MINUS);
  } else {
    setChar(6, CHAR_SPACE);
  } 
  setDigit(7, exponent);
}

void showFLU_Dec(uint8_t val)
{
  uint32_t exponent = (val & 0xF);
  uint32_t significant = (val >> 4) & 0xF;
  uint32_t fval = significant * pow2(exponent);

  Serial.print("Fval: ");
  Serial.println(fval);
  
  uint8_t firstDigit = 0;
  uint8_t maxLoop = MAX_DISPLAYS;
  uint32_t power = pow10(maxLoop - 1);
  for(int i = 0; i < maxLoop; i++) {
    uint8_t times = maxLoop - i - 1;
    uint8_t digit = (fval / power % 10);
    if (digit > 0 || firstDigit || (i + 1) == maxLoop) {
      setDigit(i, digit);
      firstDigit = 1;
    } else {
      setChar(i, CHAR_SPACE);
    }
    power /= 10;
  }
}

void displayFloatString(char *str, int len)
{
  int8_t maxLen = (int8_t)(len - 1);
  uint8_t firstNonZero = 0;
  int8_t dpIndex = -1;
  int8_t dpStrIndex = 0;
  int8_t strIndex = maxLen;
  int8_t displayIndex = MAX_DISPLAYS - 1;
  for (int8_t i = 0; i <= maxLen; i++) {
    if (str[i] == '.') {
      dpStrIndex = i;
      break;
    }
  }
  
  for (; strIndex >= 0; strIndex--) {
    char ch = str[strIndex];
    if (ch == '.') {
      if (firstNonZero) {
        dpIndex = displayIndex;
      }
    } else if (ch == '0') {
      if (firstNonZero || strIndex <= dpStrIndex) {
        setChar(displayIndex, ch);
        displayIndex--;
      }
    } else if (ch >= '1' && ch <= '9') {
      firstNonZero = 1;
      setChar(displayIndex, ch);
      displayIndex--;
    } else if (ch == '-') {
      setChar(displayIndex, ch);
      displayIndex--;
    }
  }
  if (dpIndex >= 0) {
    setDP(dpIndex, 1);
  }
  if (displayIndex == MAX_DISPLAYS - 1) {
    setChar(displayIndex, '0');
    displayIndex--;
  }
  for (; displayIndex >= 0; displayIndex--) {
    setChar(displayIndex, ' ');
  }
}

void showFLS_Dec(uint8_t val)
{
  int exponent = val & 0xF;
  int significant = (val >> 4) & 0xF;
  double fval;
  if (significant & 8) {
    if (SIGNIFICANT_TWOS_COMPLEMENT) {
      significant = -((~significant & 0xF) + 1);
    } else {
      significant = -(significant - 8);
    }
  }
  
  if (exponent & 8) {
    if (EXPONENT_TWOS_COMPLEMENT) {
      exponent = (~(exponent - 1)) & 0xF;
    } else {
      exponent -= 8;
    }
    fval = (double)(significant) / (double)pow2(exponent);
  } else {
    fval = (double)(significant) * (double)pow2(exponent);
  }

  Serial.print("Fval: ");
  Serial.println(fval, 10);

  if (fval == 0.0) {
    showSpaces();
    setDigit(MAX_DISPLAYS - 1, 0);
  }

  const int BUFFER_SIZE = 16;
  char str[BUFFER_SIZE];
  dtostrf(fval, BUFFER_SIZE, 7, str);
  Serial.print("Str: ");
  Serial.println(str);
  displayFloatString(str, BUFFER_SIZE);
}

void updateDisplayData()
{
  uint8_t val = data_value;
  switch(data_mode) {
    case 9:
      showOctal(val);
      break;
    case 1:
      showHexadecimal(val);
      break;
    case 2:
    case 10:
      showUnsigned(val);
      break;
    case 3:
      showSigned(val);
      break;
    case 4:
    case 12:
      showFXU(val);
      break;
    case 5:
      showFXS(val);
      break;
    case 6:
      showFLU(val);
      break;
    case 7:
      showFLS(val);
      break;
    case 11:
      showTwosComplement(val);
      break;
    case 13:
      showFXS_TwosComplement(val);
      break;
    case 14:
      showFLU_Dec(val);
      break;
    case 15:
      showFLS_Dec(val);
      break;
    default:
      showSpaces();
      break;
  }
}

void updateModeOutput()
{
  uint8_t output = MODE_TO_DISPLAY[data_mode];
  if (output & 1) {
    digitalWrite(PIN_A_1, HIGH);
  } else {
    digitalWrite(PIN_A_1, LOW);
  }
  
  if (output & 2) {
    digitalWrite(PIN_A_2, HIGH);
  } else {
    digitalWrite(PIN_A_2, LOW);
  }
  
  if (output & 4) {
    digitalWrite(PIN_A_3, HIGH);
  } else {
    digitalWrite(PIN_A_3, LOW);
  }

  if (output & 8) {
    digitalWrite(PIN_A_4, HIGH);
  } else {
    digitalWrite(PIN_A_4, LOW);
  }
}

void updateMultiplex()
{
  if (multiplex_display & 1) {
    digitalWrite(PIN_Z_1, HIGH);
  } else {
    digitalWrite(PIN_Z_1, LOW);
  }
  
  if (multiplex_display & 2) {
    digitalWrite(PIN_Z_2, HIGH);
  } else {
    digitalWrite(PIN_Z_2, LOW);
  }
  
  if (multiplex_display & 4) {
    digitalWrite(PIN_Z_3, HIGH);
  } else {
    digitalWrite(PIN_Z_3, LOW);
  }
}

void setup() {
  pinMode(PIN_DA, OUTPUT);
  pinMode(PIN_DB, OUTPUT);
  pinMode(PIN_DC, OUTPUT);
  pinMode(PIN_DD, OUTPUT);
  pinMode(PIN_DE, OUTPUT);
  pinMode(PIN_DF, OUTPUT);
  pinMode(PIN_DG, OUTPUT);
  pinMode(PIN_DP, OUTPUT);
  pinMode(PIN_Z_1, OUTPUT);
  pinMode(PIN_Z_2, OUTPUT);
  pinMode(PIN_Z_3, OUTPUT);
  pinMode(PIN_Z_4, OUTPUT);
  pinMode(PIN_A_1, OUTPUT);
  pinMode(PIN_A_2, OUTPUT);
  pinMode(PIN_A_3, OUTPUT);
  pinMode(PIN_A_4, OUTPUT);
  // Pin A4 and Z4 are always LOW
  digitalWrite(PIN_A_4, LOW);
  digitalWrite(PIN_Z_4, LOW);
  
  Serial.begin(9600);
  // Start the I2C Bus as Slave on address 9
  Wire.begin(9);
  // Attach a function to trigger when something is received.
  Wire.onReceive(receiveEvent);
}

void receiveEvent(int data) {
  data_mode = Wire.read();
  data_value = Wire.read();
  //Serial.print("Mode: ");
  //Serial.println(data_mode);
  //Serial.print("Value: ");
  //Serial.println(data_value);
  updateModeOutput();
  updateDisplayData();
}

void loop() {
  updateMultiplex();
  updateDisplay(multiplex_display);
  
  multiplex_display++;
  if (multiplex_display >= MAX_DISPLAYS) {
    multiplex_display = 0;
  }
  delay(2);
}

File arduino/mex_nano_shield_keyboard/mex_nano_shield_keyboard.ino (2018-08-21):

#include <Wire.h>

// Port A
#define PIN_A_1  A3
#define PIN_A_2  A2
#define PIN_A_3  A1
#define PIN_A_4  A0
// Port B is used for I2C

// Port X
#define PIN_X_1  8
#define PIN_X_2  7
#define PIN_X_3  6
#define PIN_X_4  5
// Port Y
#define PIN_Y_1  4
#define PIN_Y_2  3
#define PIN_Y_3  2
#define PIN_Y_4  9
// Port Z
#define PIN_Z_1   10
#define PIN_Z_2   11
#define PIN_Z_3   12
#define PIN_Z_4   13

// the available modes
#define MODE_NUL 0
#define MODE_OCT 1
#define MODE_HEX 2
#define MODE_DCU 3
#define MODE_DCS 4
#define MODE_FXU 5
#define MODE_FXS 6
#define MODE_FLU 7
#define MODE_FLS 8

#define KEYBOARD_NO_KEY 0xFF

uint8_t data_mode = 0;
uint8_t data_value = 0;

int outPinArray[] = {10, 11, 12, 13}; // KEY IN
int inPinArray[] = {17, 16, 15, 14};  // KEY out  /Reihenfolge invertiert

/*
 * read analog value and convert to digital
 */
uint8_t getDigital(int analogPin)
{
  int val = analogRead(analogPin);
  if( val > 300) {
    return HIGH;
  } else {
    return LOW;
  }
}

/**
 * get pressed key of keyboard (Z-Out, A-In)
 */
uint8_t getKeyboardKey()
{
  digitalWrite(PIN_Z_4, HIGH);
  digitalWrite(PIN_Z_1, LOW);
  if (!getDigital(PIN_A_1)) {
    return 0;
  } else if (!getDigital(PIN_A_2)) {
    return 4;
  } else if (!getDigital(PIN_A_3)) {
    return 8;
  } else if (!getDigital(PIN_A_4)) {
    return 0xC;
  }
  digitalWrite(PIN_Z_1, HIGH);
  digitalWrite(PIN_Z_2, LOW);
  if (!getDigital(PIN_A_1)) {
    return 1;
  } else if (!getDigital(PIN_A_2)) {
    return 5;
  } else if (!getDigital(PIN_A_3)) {
    return 9;
  } else if (!getDigital(PIN_A_4)) {
    return 0xD;
  }
  digitalWrite(PIN_Z_2, HIGH);
  digitalWrite(PIN_Z_3, LOW);
  if (!getDigital(PIN_A_1)) {
    return 2;
  } else if (!getDigital(PIN_A_2)) {
    return 6;
  } else if (!getDigital(PIN_A_3)) {
    return 0xA;
  } else if (!getDigital(PIN_A_4)) {
    return 0xE;
  }
  digitalWrite(PIN_Z_3, HIGH);
  digitalWrite(PIN_Z_4, LOW);
  if (!getDigital(PIN_A_1)) {
    return 3;
  } else if (!getDigital(PIN_A_2)) {
    return 7;
  } else if (!getDigital(PIN_A_3)) {
    return 0xB;
  } else if (!getDigital(PIN_A_4)) {
    return 0xF;
  }
  return KEYBOARD_NO_KEY;
}

uint8_t getKey()
{
  // Tastatur - KEY-IN-A auf ANS-Z, KEY-OUT-X auf ANS-A
  for (int intOut = 0; intOut <= 3; intOut++) // KEY ablesen und speichern in intKeyboard
  {
    digitalWrite(outPinArray[intOut], LOW); // aktuelle Reihe auf 0
    for (int intIn = 0; intIn <= 3; intIn++) // Spalten ablesen
    {
      int intRead = analogRead(inPinArray[intIn]); // lesen analog wegen ew. Diodenkombinationen
      if (intRead < 400) // Grenze 1/0 (0-1024)
        return intOut + intIn * 4; // ermittlung der Tastennummern
    }
    digitalWrite(outPinArray[intOut], HIGH); // Reieh auf 1
  }
  return KEYBOARD_NO_KEY;
}

uint8_t getABinary()
{
  uint8_t val = 0;
  val |= getDigital(PIN_A_1);
  val |= getDigital(PIN_A_2) << 1;
  val |= getDigital(PIN_A_3) << 2;
  val |= getDigital(PIN_A_4) << 3;
  return val;
}

/**
 * get combined value of X + Y (one byte)
 */
uint8_t getValueXY()
{
  uint8_t val = digitalRead(PIN_X_1);
  val |= digitalRead(PIN_X_2) << 1;
  val |= digitalRead(PIN_X_3) << 2;
  val |= digitalRead(PIN_X_4) << 3;
  val |= digitalRead(PIN_Y_1) << 4;
  val |= digitalRead(PIN_Y_2) << 5;
  val |= digitalRead(PIN_Y_3) << 6;
  val |= digitalRead(PIN_Y_4) << 7;
  return val;
}

void setup() {
  pinMode(PIN_A_1, INPUT);
  pinMode(PIN_A_2, INPUT);
  pinMode(PIN_A_3, INPUT);
  pinMode(PIN_A_4, INPUT);
  pinMode(PIN_X_1, INPUT);
  pinMode(PIN_X_2, INPUT);
  pinMode(PIN_X_3, INPUT);
  pinMode(PIN_X_4, INPUT);
  pinMode(PIN_Y_1, INPUT);
  pinMode(PIN_Y_2, INPUT);
  pinMode(PIN_Y_3, INPUT);
  pinMode(PIN_Y_4, INPUT);
  pinMode(PIN_Z_1, OUTPUT);
  pinMode(PIN_Z_2, OUTPUT);
  pinMode(PIN_Z_3, OUTPUT);
  pinMode(PIN_Z_4, OUTPUT);
  digitalWrite(PIN_Z_1, HIGH);
  digitalWrite(PIN_Z_2, HIGH);
  digitalWrite(PIN_Z_3, HIGH);
  digitalWrite(PIN_Z_4, HIGH);

  Serial.begin(9600);
  // Start the I2C Bus as Master
  Wire.begin(); 
}

void loop() {
  uint8_t key = getABinary();
  uint8_t value = getValueXY();
  //Serial.print("Key: ");
  //Serial.println(key);
  //Serial.print("Value: ");
  //Serial.println(value);
  if (key != data_mode || value != data_value) {
    if (key != KEYBOARD_NO_KEY) {
      data_mode = key;
    }
    data_value = value;
    Wire.beginTransmission(9); 
    Wire.write(data_mode);    
    Wire.write(data_value);    
    Wire.endTransmission(); 
  }
  delay(250);   
}

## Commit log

2016-06-22 Initial Commit of Mexdulon Documentation: License, changes and product file, pdf folder. Schematics in PDF files for 25 Mexdulon modules.
2016-10-28 +doc folder with schematics as pdf and layouts as png +eagle folder with brd and sch files (eagle cadsoft) +bom folder with bom files as csv +files for 16 boards v1.1: Adapter, Adder, AND_NAND, BCD_7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
    [AND_NAND_1.1.brd, AND_NAND_1.1.csv, AND_NAND_1.1.sch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]
2016-10-29 *doc/Aufbau_der_Bausaetze updated +(Dioden, LEDs, Segment-Displays)
2016-10-29 +assembly folder with pdf files for assembly information
2016-10-29 *doc/Aufbau_der_Bausaetze.pdf -> assembly/Aufbau_der_Bausaetze.pdf *assembly/Aufbau_der_Bausaetze.pdf updated
2016-10-29 -doc/*.png images removed (duplicates in assembly)
2016-10-30 +lib-Arduino folder with library files for use with Arduino (h, cpp)
2016-11-01 *arduino library folder renamed and files updated +arduino examples added
2016-11-05 *assembly/Aufbau_der_Bausaetz.pdf updated
2016-11-05 *assembly/Aufbau_der_Bausaetz.pdf updated with SI units
2016-11-18 Gerber Files for Boards v1.1 and Updates for Boards v1.0 +gerber folder added with gerber files for boards v1.1 *assembly layout images added *bom csv files added *pdf files from pdf folder switched 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
    [Arduino-Shield_1.0.csv, Binary_Counter_1.0.csv, Counter_12bit_1.0.csv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]
2017-02-18 Documentation for boards updated *pdf with schematics in 'doc' for board versions 1.1 replaced by new files *Aufbau_der_Bausaetze.pdf moved from 'assembly' to 'doc'
2017-02-18 Documentation texts for some boards v1.1 added *AND_and_NAND *Adapter *BCD_Counter *Comparator *LED_Display *Multiplexer *OR_and_NOR *Square_Wave *Universal_Register *XOR_and_XNOR
2017-02-18 BOM added into documentation for boards v1.1
2017-02-18 Documentation files for boards v1.1 moved to /doc/deutsch
2017-02-22 New documentation files for boards +Analog_Multiplexer_1_0 +Arduino_Shield_1_0 +Counter_12bit_1_0 +Counter_1_0 +Decoder_1_0 +Dot_Matrix_Display_1_0 +Inverter_1_0 +JK_Flip-flop_1_0 +Jumper_Adapter_1_0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
2017-02-22 Cleaning up repository *bom folder removed (boms are in documentation files) *assembly folder removed (pictures are in documentation files)
    [AND_NAND_1.1.csv, Adapter_1.1.csv, Adder_1.1.csv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]
2017-04-12 Documentation updated
    *AND_and_NAND_1_1
    *Adder_1_1
    *Arduino_Shield_1_0
    *BCD_7SD_Decoder_1_1
    *Counter_12bit_1_0
2017-09-29 Files renamed to new board codes
    [7SD_1_1.brd, 7SD_1_1.sch, ADA_1_1.brd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]
2017-09-29 Update README.md
    table with all boards added
2017-09-30 tetraBoards_Uebersicht_Beschreibung added
    csv file for board overview added
    [tetraBoards_Uebersicht_Beschreibung.csv]
2017-09-30 Delete tetraBoards_Uebersicht_Beschreibung.csv
    this format is wrong, therefore file deleted
    [tetraBoards_Uebersicht_Beschreibung.csv]
2017-09-30 tetraBoards_Uebersicht_Beschreibung.tsv added
    [tetraBoards_Uebersicht_Beschreibung.tsv]
2017-10-13 eagle files and png images for several boards added: ADC_1_0 ANS_1_1 ARD_1_0 BNC_1_1 C12_1_0 CLK_1_1 CNT_1_0 DAC_1_0 DEC_1_0 DFF_1_0 DMD_1_0 DMX_1_0 ENC_1_1 FET_1_0 INV_1_0 IOP_1_1 JAD_1_0 JKF_1_0 JO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
    [ADC_1_0.brd, ADC_1_0.sch, ANS_1_1.brd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]
2017-10-21 warning fixes and comments added
    [mex_nano_shield_display.ino]
2017-11-03 New board files with schematics and silk screen layouts +ALU_1_0, CNT_1_1, D12_1_0, D14_1_0, D18_1_0, DIP_1_0, M81_1_0, N33_1_0, SWI_1_1 *SOC_1_0 modified (bigger label)
2017-11-03 New boards: eagle files (sch, brd) +ALU_1_0, CNT_1_1, D12_1_0, D14_1_0, D18_1_0, DIP_1_0, M81_1_0, N33_1_0, SWI_1_1 *SOC_1_0 modified
    [ALU_1_0.brd, ALU_1_0.sch, CNT_1_1.brd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]
2017-11-03 tetraBoards_Uebersicht update neue Boards
    [tetraBoards_Uebersicht_Beschreibung.tsv]
2017-11-03 tetraBoards_Uebersicht updated
    [tetraBoards_Uebersicht_Beschreibung.tsv]
2018-04-12 new boards (eagle files) and updated LAD_1_1 +DLS_1_0 +NOT_1_0 +PWR_1_0 +TFF_1_0 *LAD_1_1
    [DLS_1_0.brd, DLS_1_0.sch, LAD_1_1.brd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]
2018-04-16 tetraBoards_Uebersicht updated with categories
    [tetraBoards_Uebersicht_Beschreibung.tsv]
2018-04-16 tetraBoards_Uebersicht corrected some names
    [tetraBoards_Uebersicht_Beschreibung.tsv]
2018-04-19 IOP 1.0 added
    [IOP_1_0.brd, IOP_1_0.sch]
2018-04-19 Missing doc files added, schematics.pdf created +doc/pdf/schematics.pdf: all schematics in one file
    [PWR_1_0.brd, PWR_1_0.sch, RGB_1_1b.brd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]
2018-08-21 Add new tetra-Board and arduino files
    Add AMP_1_0, AVC_1_0, D18_1_1, IOP_1_2, MIC_1_0, PIN_1_1, POT_1_0, PWA_1_0, PWR_1_0, RGF 2.0, SOC_2_0, VLT_1_0
    Add mex_nano_shield_keyboard, mex_nano_shied_numbers
    New arduino projects
    [7SD_1_1.sch, ADA_1_1.sch, ADD_1_1.sch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]
2018-09-14 Update tetraBoards_Uebersicht_Beschreibung
    Add missing boards to the table
    [tetraBoards_Uebersicht_Beschreibung.tsv]
2018-12-06 Add JMP 2.0 eagle files and images
    [JMP_2_0.brd, JMP_2_0.sch]
2018-12-06 Add eagle files and images
    for DLY, HPF, LPF, PRE, SPL, SUM
    [DLY_1_0.brd, DLY_1_0.sch, HPF_1_0.brd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]

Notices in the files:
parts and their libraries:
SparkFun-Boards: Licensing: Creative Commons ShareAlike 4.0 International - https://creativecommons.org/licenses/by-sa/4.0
